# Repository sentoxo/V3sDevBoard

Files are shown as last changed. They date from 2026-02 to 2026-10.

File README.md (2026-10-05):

# V3sDevBoard
Educational project of first PCB desgin, SBC with linux built on allwinner V3s SoC.  

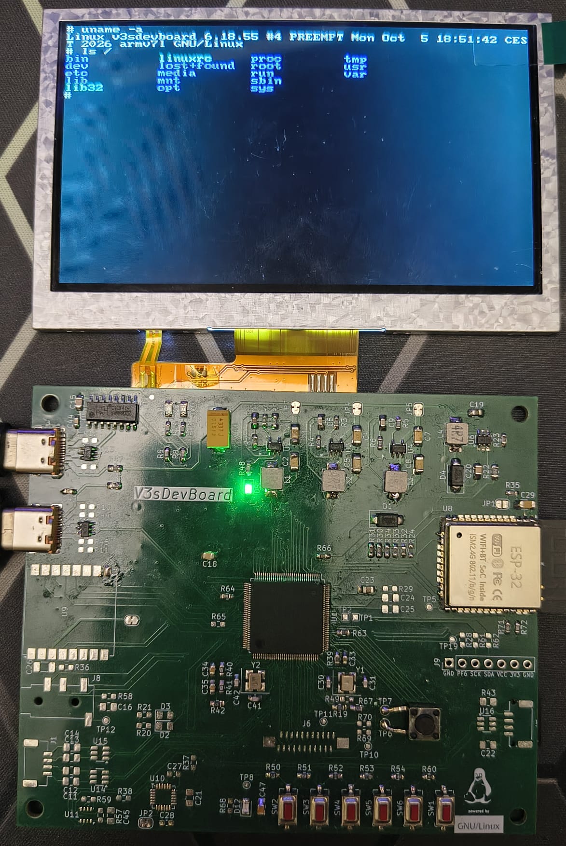
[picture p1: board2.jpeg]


## SYSTEM SPECIFICATIONS
=====================

### CORE SYSTEM:
- CPU: Allwinner V3s (ARM Cortex-A7 @ 1.2GHz)
- RAM: 64MB DDR2 @ 400MHz (Integrated SiP)
- STORAGE: SD Interface for OS (SDIO compatible)

### CONNECTIVITY:
- ETHERNET: 100Mbps Interface
- WIRELESS: WiFi & Bluetooth (via ESP32[ESP-Hosted-NG] on SDIO/UART) {PG0-5 -> SDIO, PB0-1 -> UART}
- LONG RANGE: LoRa support (via Ra-02 on SPI) {PB2 -> RESET, PB3 -> INT, PC0-3 -> SPI}
- USB: USB Host support (Simple)
- DEBUG: System UARTs to USB bridge

### DISPLAY & IMAGING:
- CAMERA: MIPI CSI (22-pin connector)
- LCD: RGB-666 Interface with backlight support (40-pin) [ST7280] {PB4 -> LC_LED_PWM, PE0-19,23-24}

### SENSORS & I/O:
- MOTION: MPU6050 Accelerometer & Gyroscope [I2C] {PB6-7}
- ENVIRONMENT: BME280 Sensor (Temp/Press/Hum) [I2C] {PB6-7}
- AUDIO: 3.5mm Audio Jack
- INPUT: Low-resolution ADC for button matrix (6 buttons)
- VISUAL: PCB RGB backlight WS2812B {PB5}

### POWER & SOFTWARE:
- REGULATION: DC-DC converters for 3.3V, 1.8V, 1.2V
- OPERATING SYSTEM: Powered by custom Mainline Linux

=====================
## Errata for revA
- Ther was mistake in SDIO for SDCard. Swaped data lines.
- RTC didn't have power without battery.

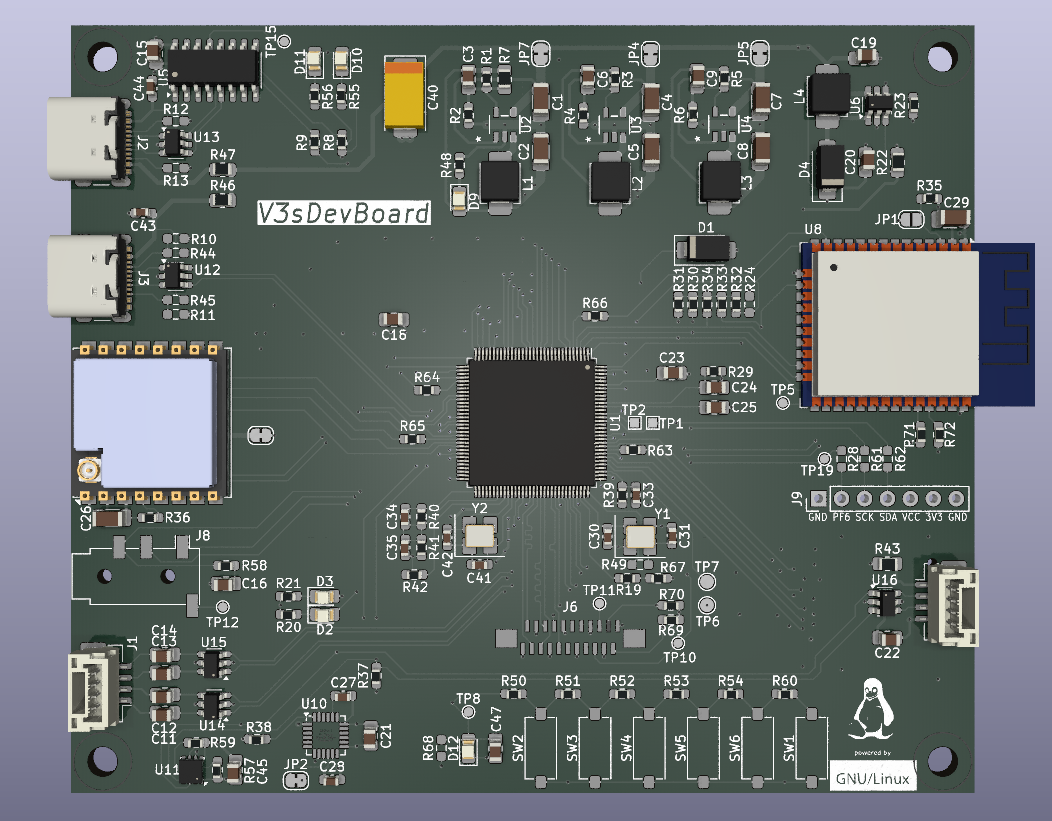
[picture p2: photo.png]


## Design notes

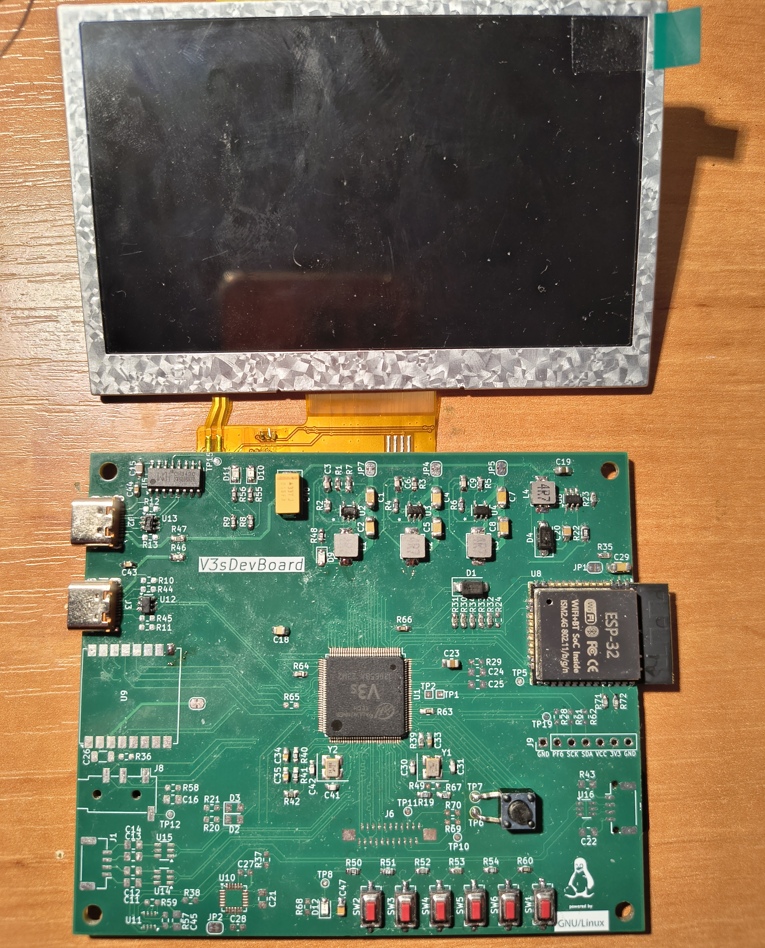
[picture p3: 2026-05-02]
board.jpg

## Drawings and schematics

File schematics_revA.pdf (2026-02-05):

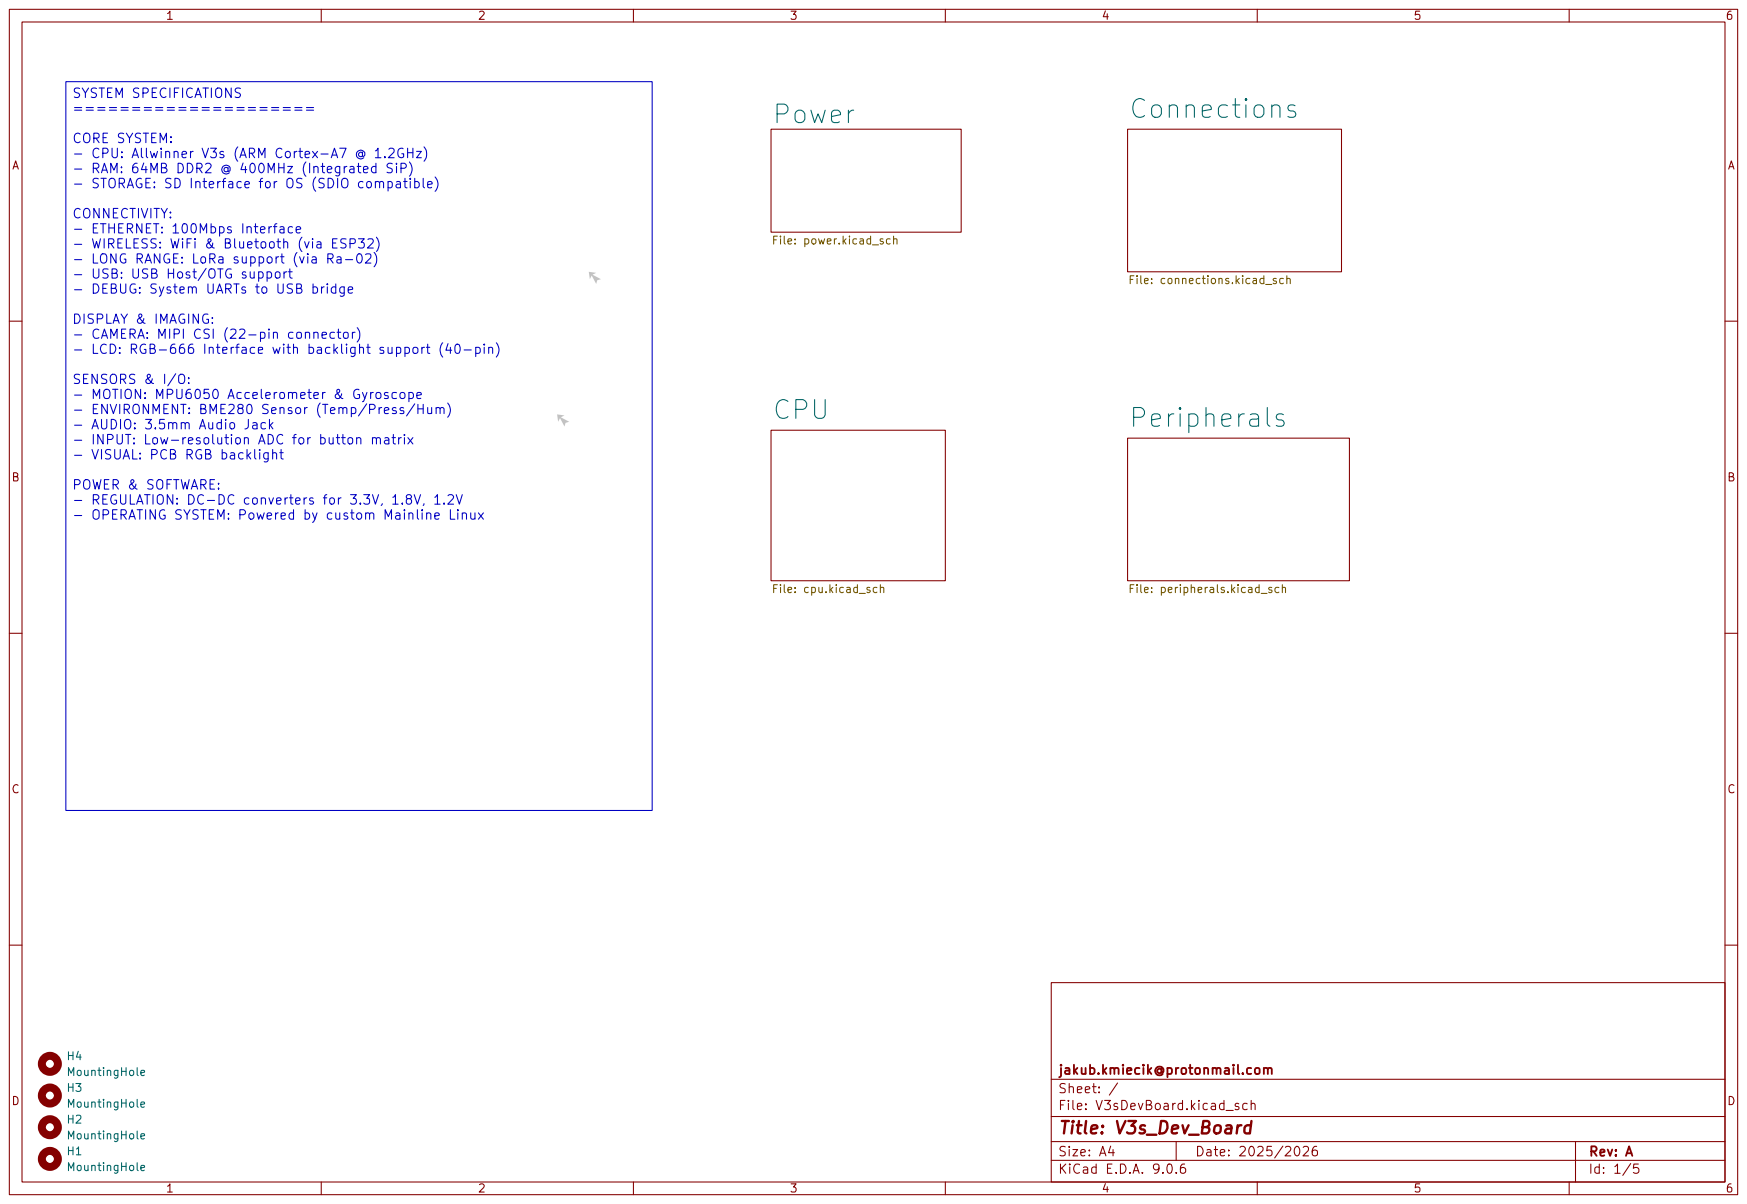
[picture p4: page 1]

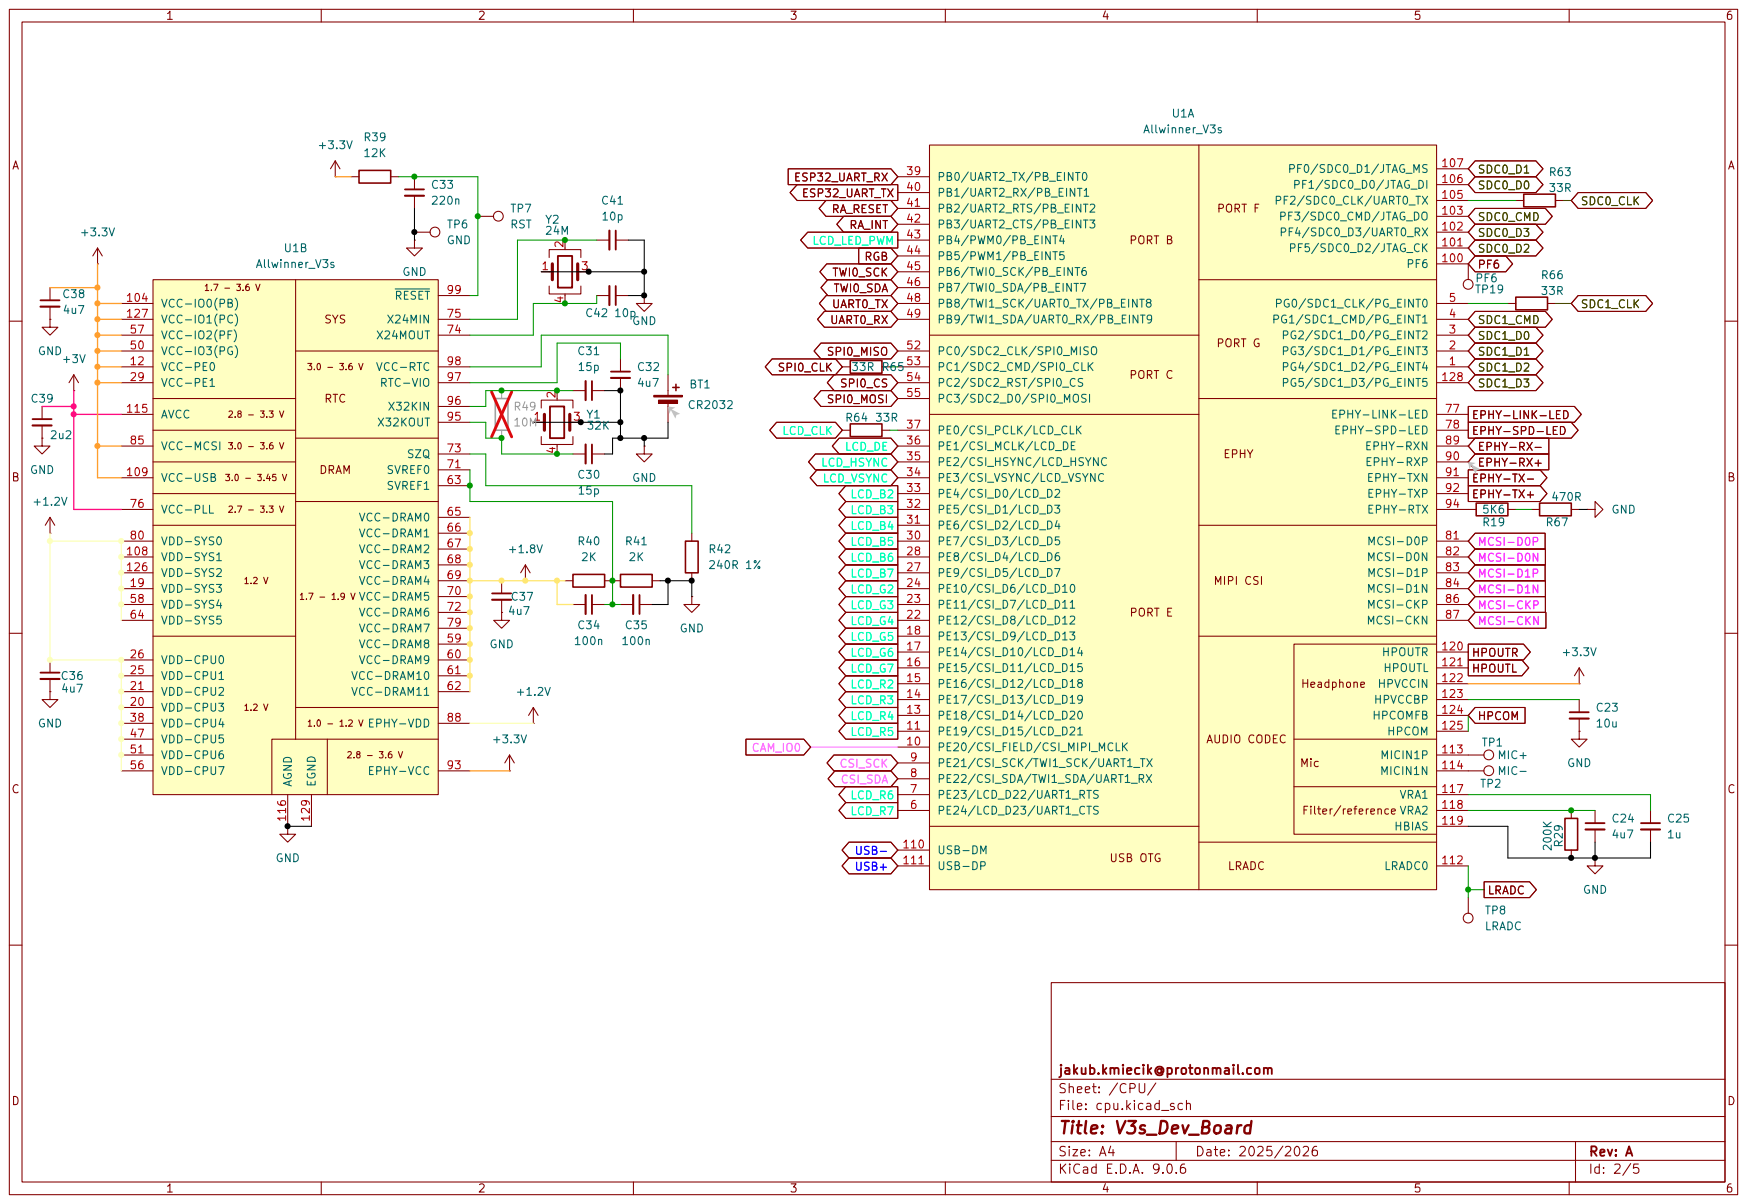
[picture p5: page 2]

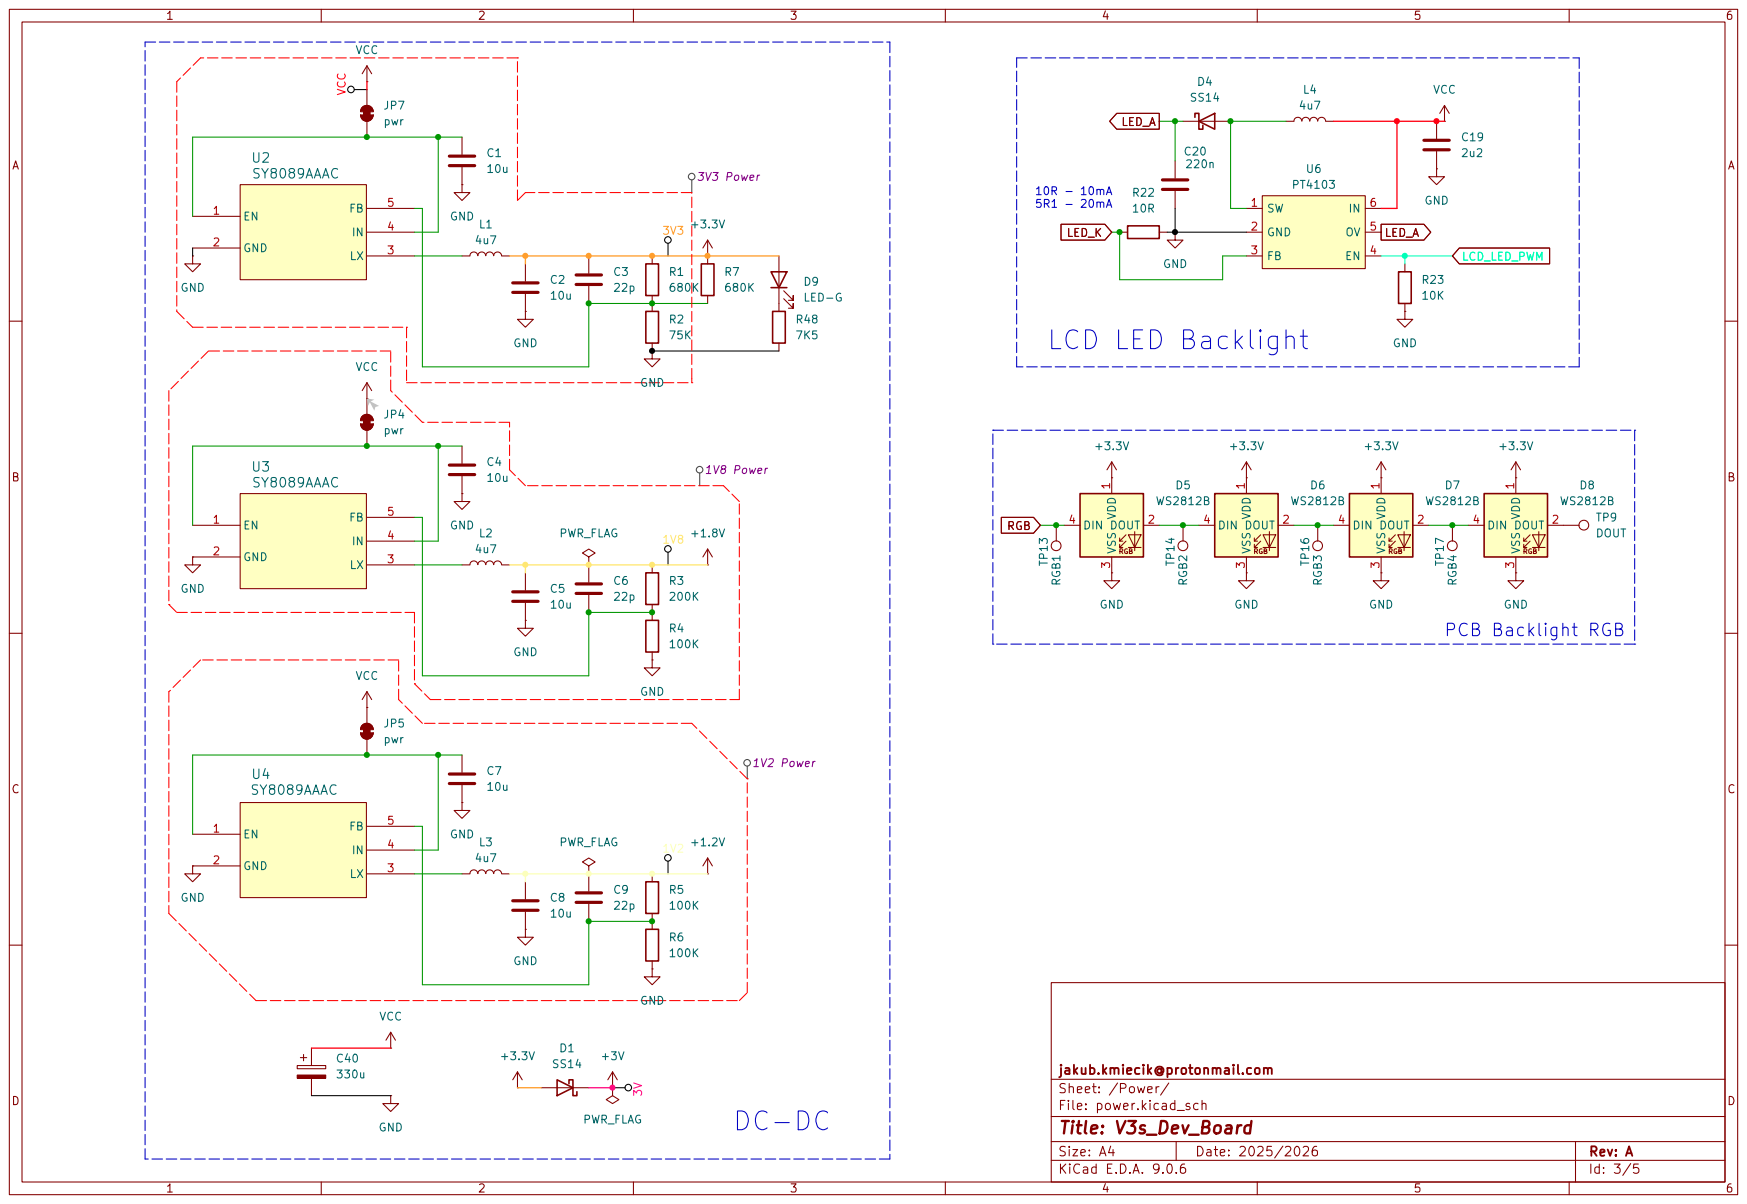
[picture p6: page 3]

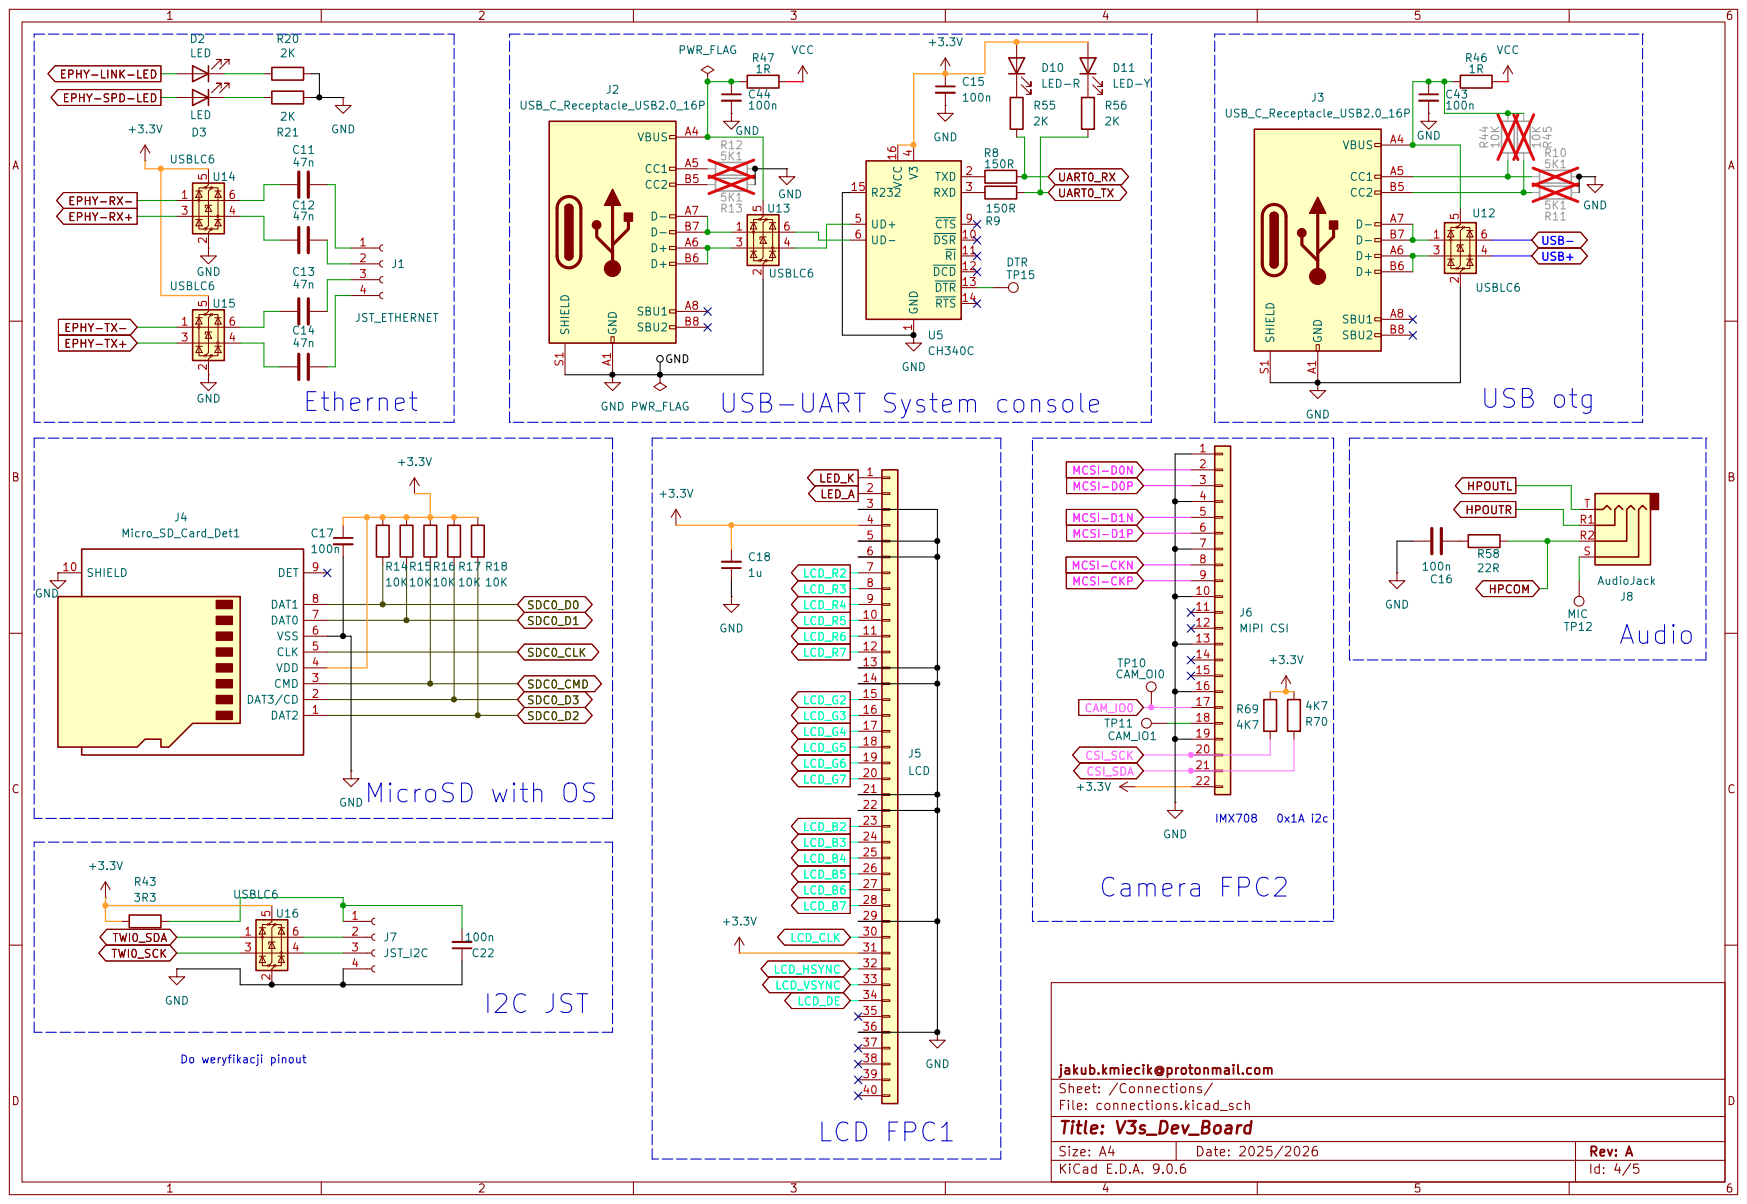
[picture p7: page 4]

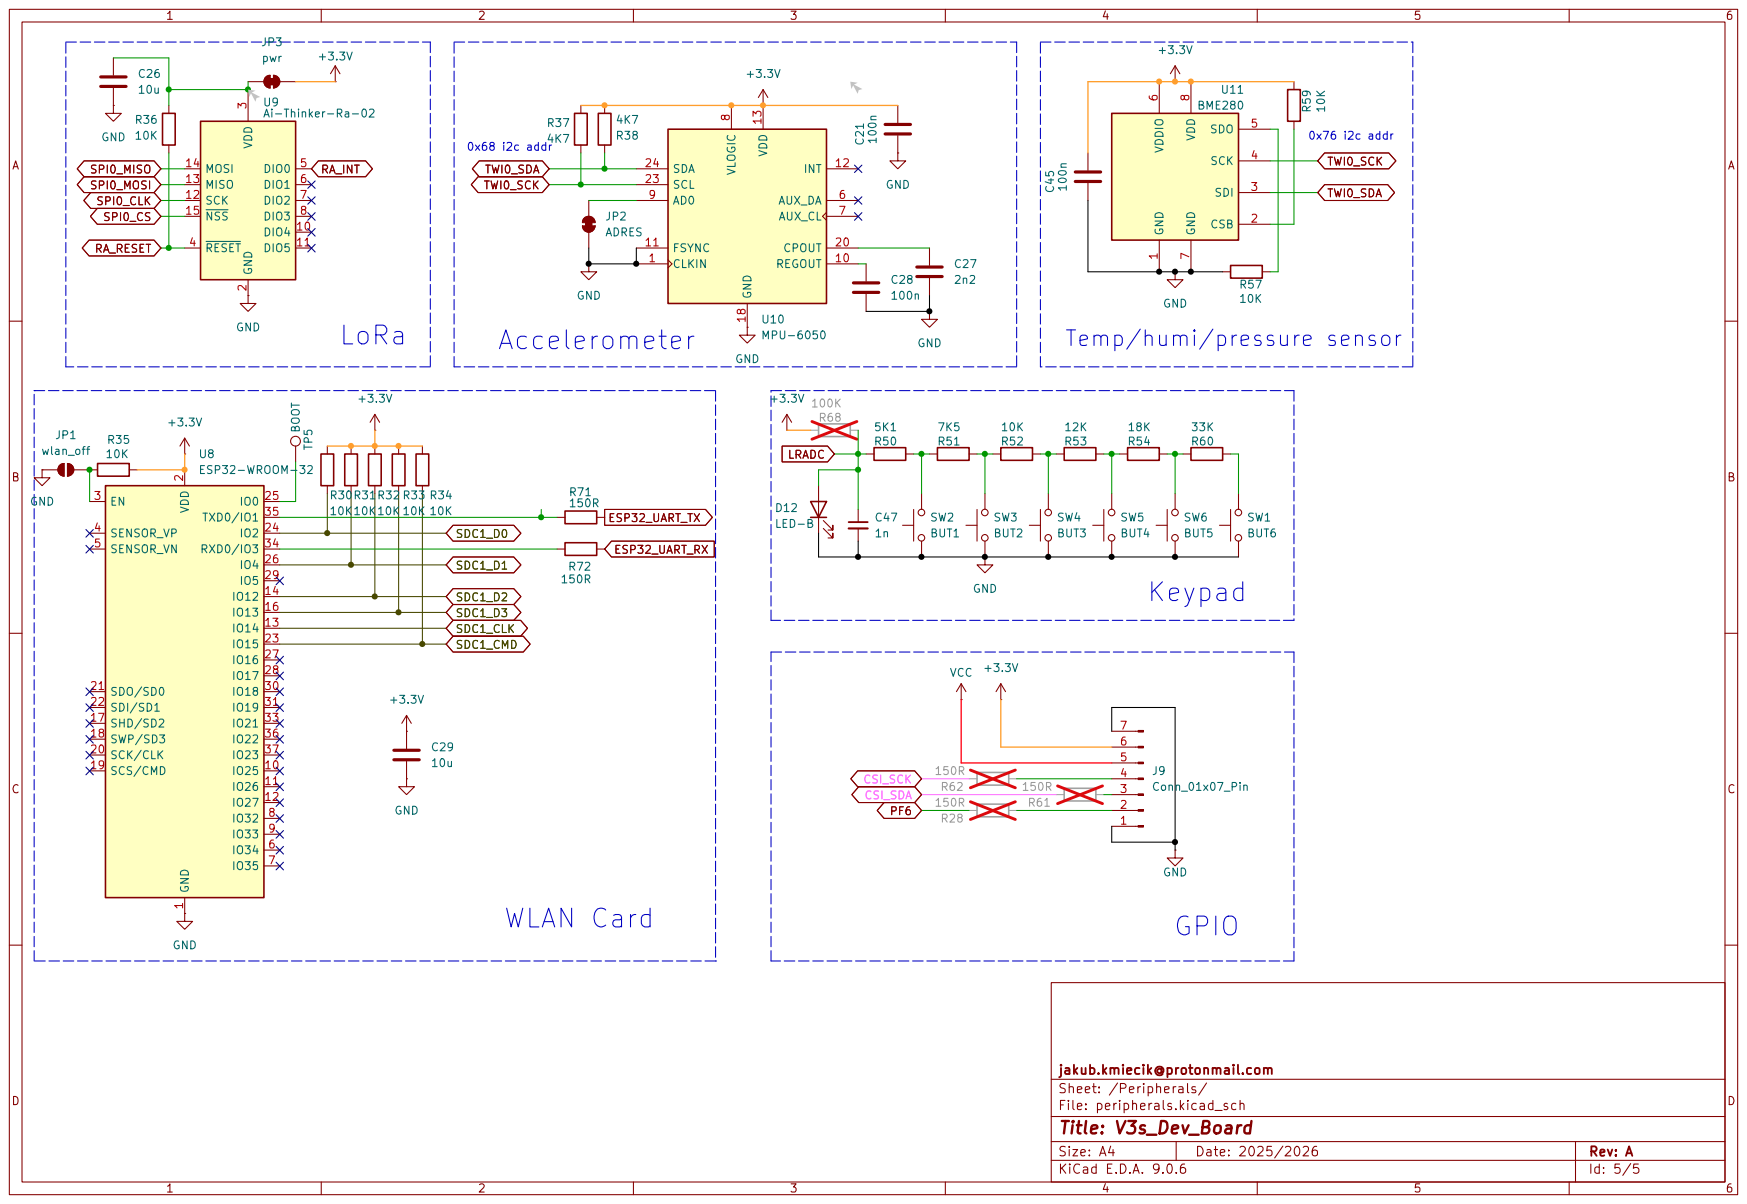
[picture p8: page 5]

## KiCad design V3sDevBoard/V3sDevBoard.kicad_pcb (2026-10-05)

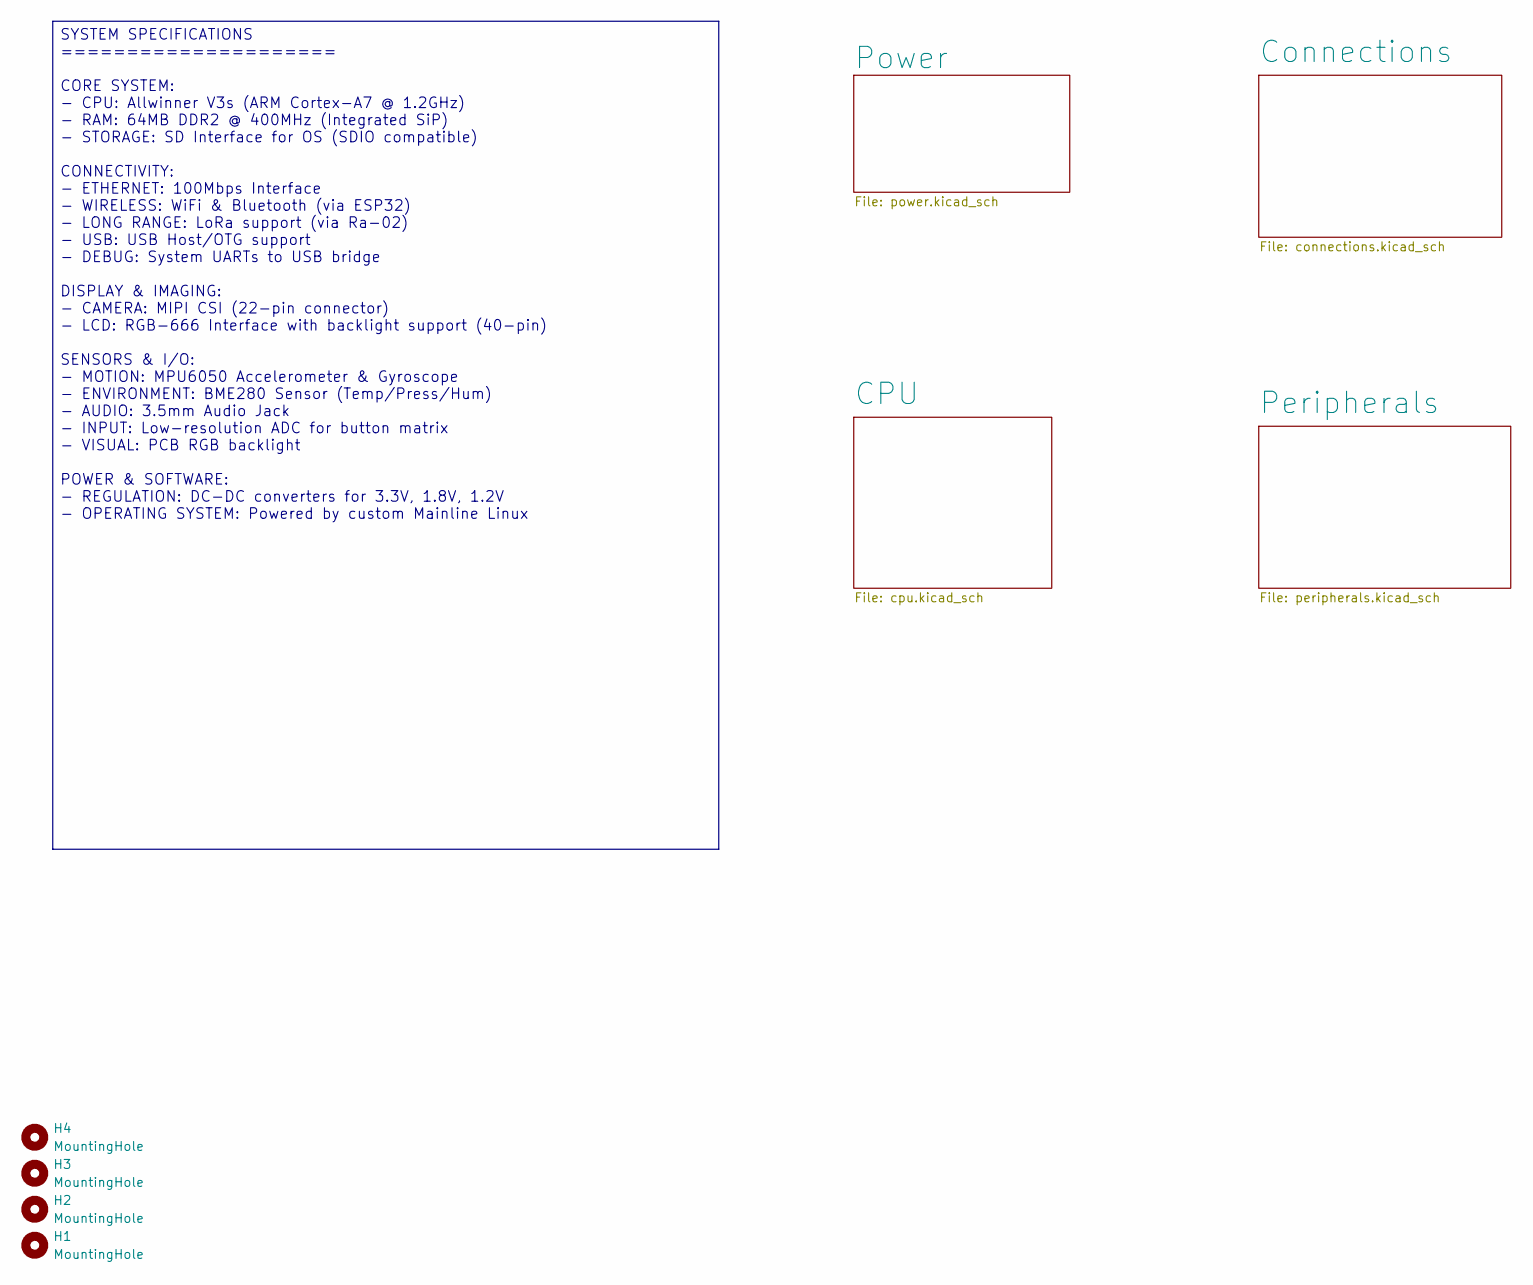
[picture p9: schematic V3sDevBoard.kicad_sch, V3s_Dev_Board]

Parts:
H1, H2, H3, H4: MountingHole; MountingHole_3.2mm_M3

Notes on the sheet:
SYSTEM SPECIFICATIONS ===================== CORE SYSTEM: - CPU: Allwinner V3s (ARM Cortex-A7 @ 1.2GHz) - RAM: 64MB DDR2 @ 400MHz (Integrated SiP) - STORAGE: SD Interface for OS (SDIO compatible) CONNECTIVITY: - ETHERNET: 100Mbps Interface - WIRELESS: WiFi & Bluetooth (via ESP32) - LONG RANGE: LoRa 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

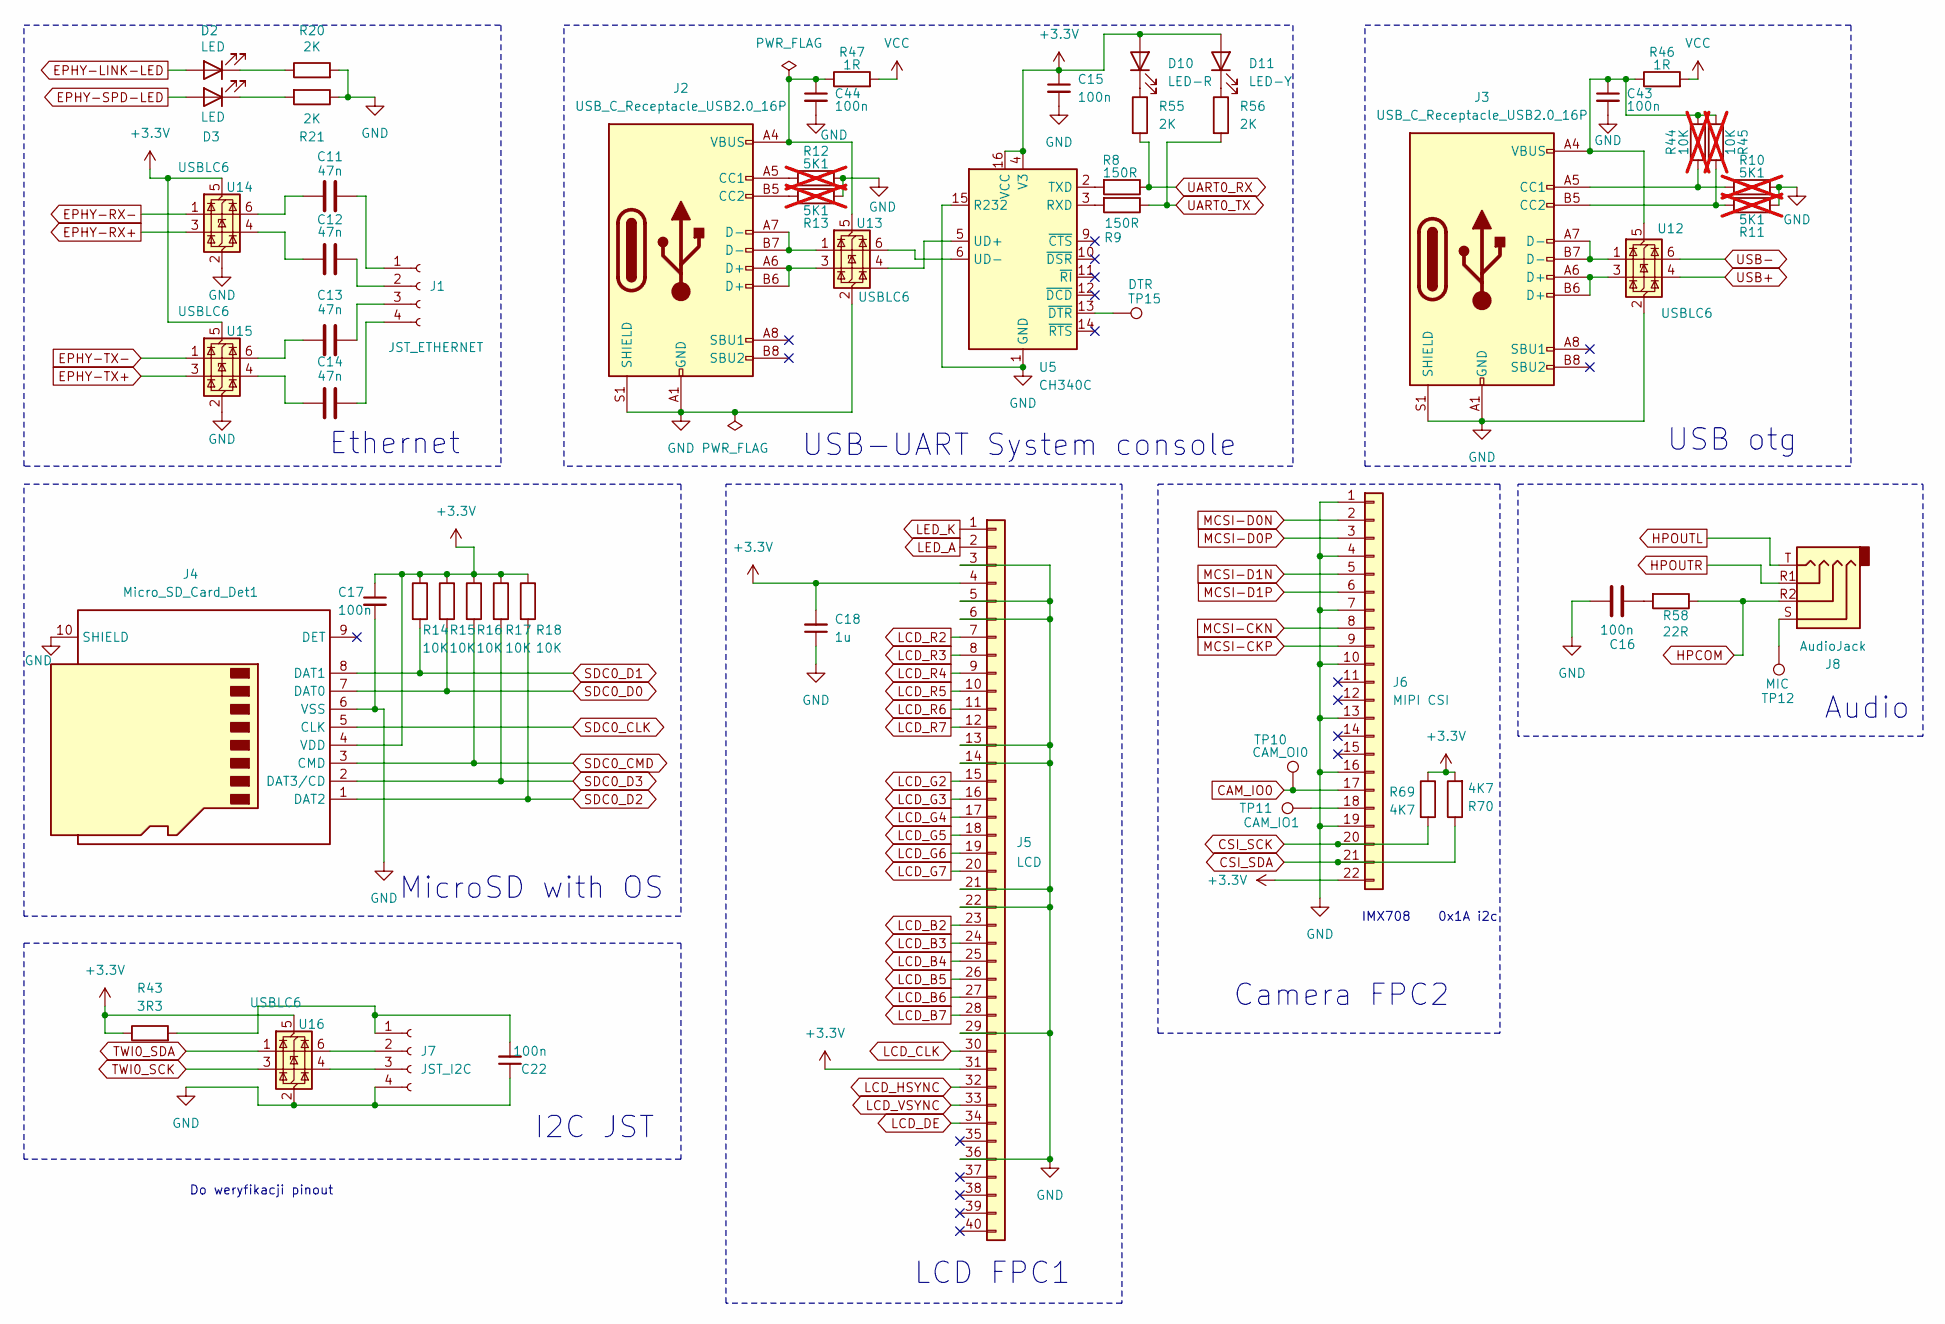
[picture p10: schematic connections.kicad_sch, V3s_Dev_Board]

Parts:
C11, C12, C13, C14: 47n; C_0805_2012Metric_Pad1.18x1.45mm_HandSolder
C15, C16, C17, C22: 100n; C_0805_2012Metric_Pad1.18x1.45mm_HandSolder
C18: 1u; C_0805_2012Metric_Pad1.18x1.45mm_HandSolder
C43, C44: 100n; C_0603_1608Metric_Pad1.08x0.95mm_HandSolder
D2, D3: LED; LED_0805_2012Metric_Pad1.15x1.40mm_HandSolder
D10: LED-R; LED_0805_2012Metric_Pad1.15x1.40mm_HandSolder
D11: LED-Y; LED_0805_2012Metric_Pad1.15x1.40mm_HandSolder
J1: JST_ETHERNET; JST_GH_BM04B-GHS-TBT_1x04-1MP_P1.25mm_Vertical
J2, J3: USB_C_Receptacle_USB2.0_16P; USB_C_Receptacle_GCT_USB4105-xx-A_16P_TopMnt_Horizontal
J4: Micro_SD_Card_Det1; microSD
J5: LCD; Amphenol_F32Q-1A7x1-11040_1x40-1MP_P0.5mm_Horizontal
J6: MIPI CSI; FPC_1x22-1MP_P0.5mm_Vertical
J7: JST_I2C; JST_GH_BM04B-GHS-TBT_1x04-1MP_P1.25mm_Vertical
J8: AudioJack; Jack_3.5mm_PJ320D_Horizontal
R8, R9: 150R; R_0603_1608Metric_Pad0.98x0.95mm_HandSolder
R10, R11, R12, R13: 5K1; R_0603_1608Metric_Pad0.98x0.95mm_HandSolder; not fitted
R14, R15, R16, R17, R18: 10K; R_0603_1608Metric_Pad0.98x0.95mm_HandSolder
R20, R21, R55, R56: 2K; R_0603_1608Metric_Pad0.98x0.95mm_HandSolder
R43: 3R3; R_0805_2012Metric_Pad1.20x1.40mm_HandSolder
R44, R45: 10K; R_0603_1608Metric_Pad0.98x0.95mm_HandSolder; not fitted
R46, R47: 1R; R_0805_2012Metric
R58: 22R; R_0603_1608Metric_Pad0.98x0.95mm_HandSolder
R69, R70: 4K7; R_0603_1608Metric_Pad0.98x0.95mm_HandSolder
TP10: CAM_OI0; TestPoint_Pad_D1.0mm
TP11: CAM_IO1; TestPoint_Pad_D1.0mm
TP12: MIC; TestPoint_Pad_D1.0mm
TP15: DTR; TestPoint_Pad_D1.0mm
U5: CH340C; SOIC-16_3.9x9.9mm_P1.27mm
U12, U13, U14, U15, U16: USBLC6; SOT-23-6

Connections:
+3.3V: C15.1, C17.1, C18.2, D10.2 (A), D11.2 (A), J4.4 (VDD), J5.4, J5.31, J6.22, R14.1, R15.1, R16.1, R17.1, R18.1, R43.1, R69.1, R70.2, U5.4 (V3), U5.16 (VCC), U14.5 (VBUS), U15.5 (VBUS), U16.5 (VBUS); also elsewhere on the board
CAM_IO0: J6.17, TP10.1 (1_1); also elsewhere on the board
CSI_SCK: J6.20, R69.2; also elsewhere on the board
CSI_SDA: J6.21, R70.1; also elsewhere on the board
EPHY-LINK-LED: D2.2 (A); also elsewhere on the board
EPHY-RX+: U14.3 (I/O2); also elsewhere on the board
EPHY-RX-: U14.1 (I/O1); also elsewhere on the board
EPHY-SPD-LED: D3.2 (A); also elsewhere on the board
EPHY-TX+: U15.3 (I/O2); also elsewhere on the board
EPHY-TX-: U15.1 (I/O1); also elsewhere on the board
GND: C15.2, C16.2, C17.2, C18.1, C22.1, C43.2, C44.2, J2.A1 (GND), J2.A12 (GND), J2.B1 (GND), J2.B12 (GND), J2.S1 (SHIELD), J3.A1 (GND), J3.A12 (GND), J3.B1 (GND), J3.B12 (GND), J3.S1 (SHIELD), J4.6 (VSS), J4.10 (SHIELD), J5.3, J5.5, J5.6, J5.13, J5.14, J5.21, J5.22, J5.29, J5.36, J6.1, J6.4, J6.7, J6.10, J6.13, J6.16, J6.19, J7.4, R10.2, R11.1, R12.2, R13.1, R20.2, R21.1, U5.1 (GND), U5.15 (R232), U12.2 (GND), U13.2 (GND), U14.2 (GND), U15.2 (GND), U16.2 (GND); also elsewhere on the board
HPCOM: J8.R2, R58.1; also elsewhere on the board
HPOUTL: J8.T; also elsewhere on the board
HPOUTR: J8.R1; also elsewhere on the board
LCD_B2: J5.23; also elsewhere on the board
LCD_B3: J5.24; also elsewhere on the board
LCD_B4: J5.25; also elsewhere on the board
LCD_B5: J5.26; also elsewhere on the board
LCD_B6: J5.27; also elsewhere on the board
LCD_B7: J5.28; also elsewhere on the board
LCD_CLK: J5.30; also elsewhere on the board
LCD_DE: J5.34; also elsewhere on the board
LCD_G2: J5.15; also elsewhere on the board
LCD_G3: J5.16; also elsewhere on the board
LCD_G4: J5.17; also elsewhere on the board
LCD_G5: J5.18; also elsewhere on the board
LCD_G6: J5.19; also elsewhere on the board
LCD_G7: J5.20; also elsewhere on the board
LCD_HSYNC: J5.32; also elsewhere on the board
LCD_R2: J5.7; also elsewhere on the board
LCD_R3: J5.8; also elsewhere on the board
LCD_R4: J5.9; also elsewhere on the board
LCD_R5: J5.10; also elsewhere on the board
LCD_R6: J5.11; also elsewhere on the board
LCD_R7: J5.12; also elsewhere on the board
LCD_VSYNC: J5.33; also elsewhere on the board
LED_A: J5.2; also elsewhere on the board
LED_K: J5.1; also elsewhere on the board
MCSI-CKN: J6.8; also elsewhere on the board
MCSI-CKP: J6.9; also elsewhere on the board
MCSI-D0N: J6.2; also elsewhere on the board
MCSI-D0P: J6.3; also elsewhere on the board
MCSI-D1N: J6.5; also elsewhere on the board
MCSI-D1P: J6.6; also elsewhere on the board
unnamed: C11.1, U14.6 (I/O1)
unnamed: C12.1, U14.4 (I/O2)
unnamed: C13.1, U15.6 (I/O1)
unnamed: C14.1, U15.4 (I/O2)
unnamed: C16.1, R58.2
unnamed: D2.1 (K), R20.1
unnamed: D3.1 (K), R21.2
unnamed: D10.1 (K), R55.1
unnamed: D11.1 (K), R56.1
unnamed: C11.2, J1.1
unnamed: C12.2, J1.2
unnamed: C13.2, J1.3
unnamed: C14.2, J1.4
unnamed: J2.A5 (CC1), R12.1
unnamed: J2.B5 (CC2), R13.2
unnamed: J2.A6 (D+), J2.B6 (D+), U13.3 (I/O2)
unnamed: J2.A7 (D-), J2.B7 (D-), U13.1 (I/O1)
unnamed: J3.A5 (CC1), R10.1, R44.1
unnamed: J3.B5 (CC2), R11.2, R45.2
unnamed: J3.A6 (D+), J3.B6 (D+), U12.3 (I/O2)
unnamed: J3.A7 (D-), J3.B7 (D-), U12.1 (I/O1)
unnamed: J6.18, TP11.1 (1_1)
unnamed: C22.2, J7.1, R43.2
unnamed: J7.2, U16.6 (I/O1)
unnamed: J7.3, U16.4 (I/O2)
unnamed: J8.S, TP12.1 (1_1)
unnamed: R9.2, U5.3 (RXD)
unnamed: R8.2, U5.2 (TXD)
unnamed: U5.5 (UD+), U13.4 (I/O2)
unnamed: U5.6 (UD-), U13.6 (I/O1)
unnamed: TP15.1 (1_1), U5.13 (~DTR)
unnamed: C43.1, J3.A4 (VBUS), J3.A9 (VBUS), J3.B4 (VBUS), J3.B9 (VBUS), R44.2, R45.1, R46.1, U12.5 (VBUS)
unnamed: C44.1, J2.A4 (VBUS), J2.A9 (VBUS), J2.B4 (VBUS), J2.B9 (VBUS), R47.1, U13.5 (VBUS)
SDC0_CLK: J4.5 (CLK); also elsewhere on the board
SDC0_CMD: J4.3 (CMD), R16.2; also elsewhere on the board
SDC0_D0: J4.7 (DAT0), R15.2; also elsewhere on the board
SDC0_D1: J4.8 (DAT1), R14.2; also elsewhere on the board
SDC0_D2: J4.1 (DAT2), R18.2; also elsewhere on the board
SDC0_D3: J4.2 (DAT3/CD), R17.2; also elsewhere on the board
TWI0_SCK: U16.3 (I/O2); also elsewhere on the board
TWI0_SDA: U16.1 (I/O1); also elsewhere on the board
UART0_RX: R8.1, R55.2; also elsewhere on the board
UART0_TX: R9.1, R56.2; also elsewhere on the board
USB+: U12.4 (I/O2); also elsewhere on the board
USB-: U12.6 (I/O1); also elsewhere on the board
VCC: R46.2, R47.2; also elsewhere on the board

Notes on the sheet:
MicroSD with OS
LCD FPC1
Ethernet
Camera FPC2
USB otg
Audio
IMX708 0x1A i2c
USB-UART System console
Do weryfikacji pinout
I2C JST

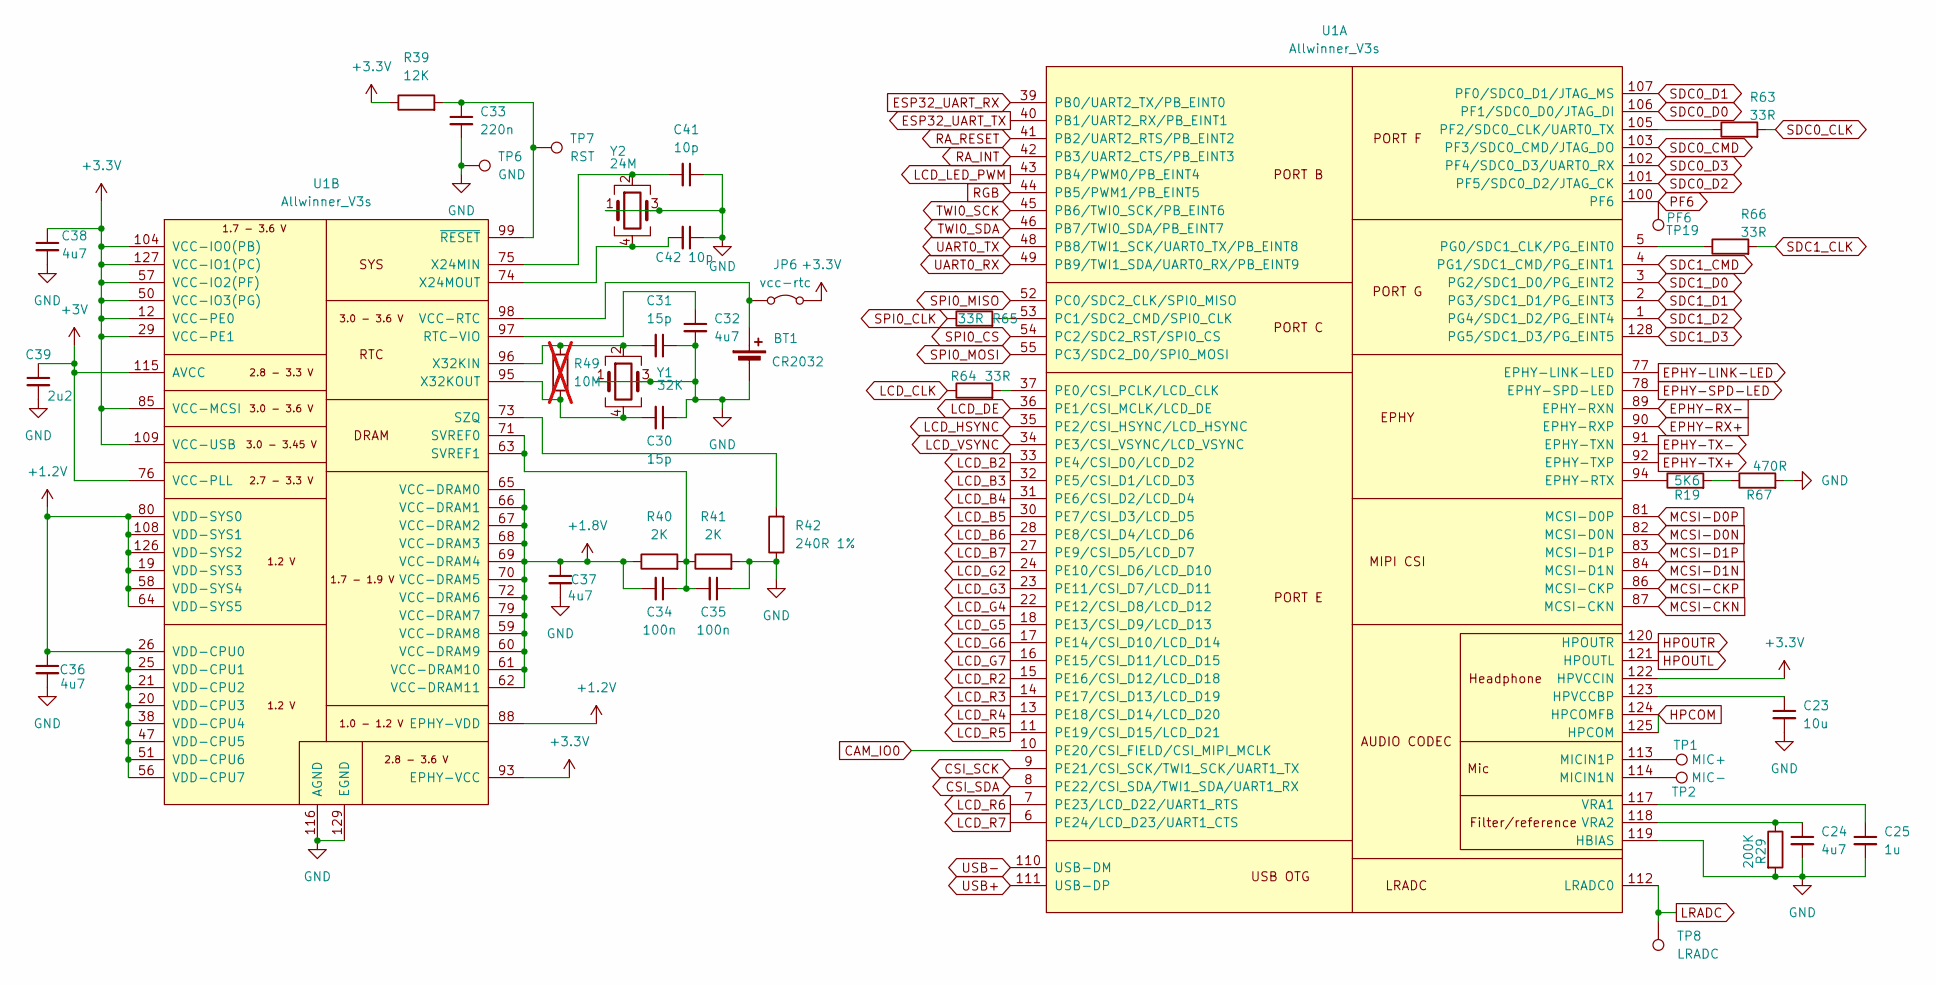
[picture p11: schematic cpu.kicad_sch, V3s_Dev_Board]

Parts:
BT1: CR2032; PinHeader_1x02_P1.00mm_Vertical_SMD_Pin1Right
C23: 10u; C_0805_2012Metric_Pad1.18x1.45mm_HandSolder
C24, C32, C36, C37, C38: 4u7; C_0805_2012Metric_Pad1.18x1.45mm_HandSolder
C25: 1u; C_0805_2012Metric_Pad1.18x1.45mm_HandSolder
C30, C31: 15p; C_0603_1608Metric_Pad1.08x0.95mm_HandSolder
C33: 220n; C_0603_1608Metric_Pad1.08x0.95mm_HandSolder
C34, C35: 100n; C_0603_1608Metric_Pad1.08x0.95mm_HandSolder
C39: 2u2; C_0805_2012Metric_Pad1.18x1.45mm_HandSolder
C41, C42: 10p; C_0603_1608Metric_Pad1.08x0.95mm_HandSolder
JP6: vcc-rtc; SolderJumper-2_P1.3mm_Bridged_RoundedPad1.0x1.5mm
R19: 5K6; R_0603_1608Metric_Pad0.98x0.95mm_HandSolder
R29: 200K; R_0603_1608Metric_Pad0.98x0.95mm_HandSolder
R39: 12K; R_0603_1608Metric_Pad0.98x0.95mm_HandSolder
R40, R41: 2K; R_0603_1608Metric_Pad0.98x0.95mm_HandSolder
R42: 240R 1%; R_0603_1608Metric_Pad0.98x0.95mm_HandSolder
R49: 10M; R_0603_1608Metric_Pad0.98x0.95mm_HandSolder; not fitted
R63, R64, R65, R66: 33R; R_0603_1608Metric_Pad0.98x0.95mm_HandSolder
R67: 470R; R_0603_1608Metric_Pad0.98x0.95mm_HandSolder
TP1: MIC+; TestPoint_Pad_1.0x1.0mm
TP2: MIC-; TestPoint_Pad_1.0x1.0mm
TP6: GND; TestPoint_Pad_D1.5mm
TP7: RST; TestPoint_Pad_D1.5mm
TP8: LRADC; TestPoint_Pad_D1.0mm
TP19: PF6; TestPoint_Pad_D1.0mm
U1: Allwinner_V3s; eLQFP-128_14x14_Pitch0.4mm_EPAD_6.60mm
Y1: 32K; Crystal_SMD_3225-4Pin_3.2x2.5mm_HandSoldering
Y2: 24M; Crystal_SMD_3225-4Pin_3.2x2.5mm_HandSoldering

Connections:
+1.2V: C36.1, U1.19 (VDD-SYS3), U1.20 (VDD-CPU3), U1.21 (VDD-CPU2), U1.25 (VDD-CPU1), U1.26 (VDD-CPU0), U1.38 (VDD-CPU4), U1.47 (VDD-CPU5), U1.51 (VDD-CPU6), U1.56 (VDD-CPU7), U1.58 (VDD-SYS4), U1.64 (VDD-SYS5), U1.80 (VDD-SYS0), U1.88 (EPHY-VDD), U1.108 (VDD-SYS1), U1.126 (VDD-SYS2); also elsewhere on the board
+1.8V: C34.2, C37.1, R40.1, U1.59 (VCC-DRAM8), U1.60 (VCC-DRAM9), U1.61 (VCC-DRAM10), U1.62 (VCC-DRAM11), U1.65 (VCC-DRAM0), U1.66 (VCC-DRAM1), U1.67 (VCC-DRAM2), U1.68 (VCC-DRAM3), U1.69 (VCC-DRAM4), U1.70 (VCC-DRAM5), U1.72 (VCC-DRAM6), U1.79 (VCC-DRAM7); also elsewhere on the board
+3.3V: C38.1, JP6.2 (B), R39.1, U1.12 (VCC-PE0), U1.29 (VCC-PE1), U1.50 (VCC-IO3(PG)), U1.57 (VCC-IO2(PF)), U1.85 (VCC-MCSI), U1.93 (EPHY-VCC), U1.104 (VCC-IO0(PB)), U1.109 (VCC-USB), U1.122 (HPVCCIN), U1.127 (VCC-IO1(PC)); also elsewhere on the board
+3V: C39.1, U1.76 (VCC-PLL), U1.115 (AVCC); also elsewhere on the board
CAM_IO0: U1.10 (PE20/CSI_FIELD/CSI_MIPI_MCLK); also elsewhere on the board
CSI_SCK: U1.9 (PE21/CSI_SCK/TWI1_SCK/UART1_TX); also elsewhere on the board
CSI_SDA: U1.8 (PE22/CSI_SDA/TWI1_SDA/UART1_RX); also elsewhere on the board
EPHY-LINK-LED: U1.77 (EPHY-LINK-LED); also elsewhere on the board
EPHY-RX+: U1.90 (EPHY-RXP); also elsewhere on the board
EPHY-RX-: U1.89 (EPHY-RXN); also elsewhere on the board
EPHY-SPD-LED: U1.78 (EPHY-SPD-LED); also elsewhere on the board
EPHY-TX+: U1.92 (EPHY-TXP); also elsewhere on the board
EPHY-TX-: U1.91 (EPHY-TXN); also elsewhere on the board
ESP32_UART_RX: U1.39 (PB0/UART2_TX/PB_EINT0); also elsewhere on the board
ESP32_UART_TX: U1.40 (PB1/UART2_RX/PB_EINT1); also elsewhere on the board
GND: BT1.2 (-), C23.2, C24.2, C25.2, C30.1, C31.1, C32.2, C33.2, C35.1, C36.2, C37.2, C38.2, C39.2, C41.1, C42.1, R29.2, R41.2, R42.1, R67.2, TP6.1 (1_1), U1.116 (AGND), U1.119 (HBIAS), U1.129 (EGND), Y1.1, Y1.3, Y2.1, Y2.3; also elsewhere on the board
HPCOM: U1.124 (HPCOMFB), U1.125 (HPCOM); also elsewhere on the board
HPOUTL: U1.121 (HPOUTL); also elsewhere on the board
HPOUTR: U1.120 (HPOUTR); also elsewhere on the board
LCD_B2: U1.33 (PE4/CSI_D0/LCD_D2); also elsewhere on the board
LCD_B3: U1.32 (PE5/CSI_D1/LCD_D3); also elsewhere on the board
LCD_B4: U1.31 (PE6/CSI_D2/LCD_D4); also elsewhere on the board
LCD_B5: U1.30 (PE7/CSI_D3/LCD_D5); also elsewhere on the board
LCD_B6: U1.28 (PE8/CSI_D4/LCD_D6); also elsewhere on the board
LCD_B7: U1.27 (PE9/CSI_D5/LCD_D7); also elsewhere on the board
LCD_CLK: R64.1; also elsewhere on the board
LCD_DE: U1.36 (PE1/CSI_MCLK/LCD_DE); also elsewhere on the board
LCD_G2: U1.24 (PE10/CSI_D6/LCD_D10); also elsewhere on the board
LCD_G3: U1.23 (PE11/CSI_D7/LCD_D11); also elsewhere on the board
LCD_G4: U1.22 (PE12/CSI_D8/LCD_D12); also elsewhere on the board
LCD_G5: U1.18 (PE13/CSI_D9/LCD_D13); also elsewhere on the board
LCD_G6: U1.17 (PE14/CSI_D10/LCD_D14); also elsewhere on the board
LCD_G7: U1.16 (PE15/CSI_D11/LCD_D15); also elsewhere on the board
LCD_HSYNC: U1.35 (PE2/CSI_HSYNC/LCD_HSYNC); also elsewhere on the board
LCD_LED_PWM: U1.43 (PB4/PWM0/PB_EINT4); also elsewhere on the board
LCD_R2: U1.15 (PE16/CSI_D12/LCD_D18); also elsewhere on the board
LCD_R3: U1.14 (PE17/CSI_D13/LCD_D19); also elsewhere on the board
LCD_R4: U1.13 (PE18/CSI_D14/LCD_D20); also elsewhere on the board
LCD_R5: U1.11 (PE19/CSI_D15/LCD_D21); also elsewhere on the board
LCD_R6: U1.7 (PE23/LCD_D22/UART1_RTS); also elsewhere on the board
LCD_R7: U1.6 (PE24/LCD_D23/UART1_CTS); also elsewhere on the board
LCD_VSYNC: U1.34 (PE3/CSI_VSYNC/LCD_VSYNC); also elsewhere on the board
LRADC: TP8.1 (1_1), U1.112 (LRADC0); also elsewhere on the board
MCSI-CKN: U1.87 (MCSI-CKN); also elsewhere on the board
MCSI-CKP: U1.86 (MCSI-CKP); also elsewhere on the board
MCSI-D0N: U1.82 (MCSI-D0N); also elsewhere on the board
MCSI-D0P: U1.81 (MCSI-D0P); also elsewhere on the board
MCSI-D1N: U1.84 (MCSI-D1N); also elsewhere on the board
MCSI-D1P: U1.83 (MCSI-D1P); also elsewhere on the board
unnamed: BT1.1 (+), JP6.1 (A), U1.98 (VCC-RTC)
unnamed: R19.2, R67.1
unnamed: R19.1, U1.94 (EPHY-RTX)
unnamed: C23.1, U1.123 (HPVCCBP)
unnamed: TP2.1 (1_1), U1.114 (MICIN1N)
unnamed: TP1.1 (1_1), U1.113 (MICIN1P)
unnamed: R65.2, U1.53 (PC1/SDC2_CMD/SPI0_CLK)
unnamed: R64.2, U1.37 (PE0/CSI_PCLK/LCD_CLK)
unnamed: R63.1, U1.105 (PF2/SDC0_CLK/UART0_TX)
unnamed: R66.1, U1.5 (PG0/SDC1_CLK/PG_EINT0)
unnamed: C25.1, U1.117 (VRA1)
unnamed: C24.1, R29.1, U1.118 (VRA2)
unnamed: C32.1, U1.97 (RTC-VIO)
unnamed: C34.1, C35.2, R40.2, R41.1, U1.63 (SVREF1), U1.71 (SVREF0)
unnamed: R42.2, U1.73 (SZQ)
unnamed: C41.2, U1.75 (X24MIN), Y2.2
unnamed: C42.2, U1.74 (X24MOUT), Y2.4
unnamed: C31.2, R49.2, U1.96 (X32KIN), Y1.2
unnamed: C30.2, R49.1, U1.95 (X32KOUT), Y1.4
unnamed: C33.1, R39.2, TP7.1 (1_1), U1.99 (~RESET)
PF6: TP19.1 (1_1), U1.100 (PF6); also elsewhere on the board
RA_INT: U1.42 (PB3/UART2_CTS/PB_EINT3); also elsewhere on the board
RA_RESET: U1.41 (PB2/UART2_RTS/PB_EINT2); also elsewhere on the board
RGB: U1.44 (PB5/PWM1/PB_EINT5); also elsewhere on the board
SDC0_CLK: R63.2; also elsewhere on the board
SDC0_CMD: U1.103 (PF3/SDC0_CMD/JTAG_DO); also elsewhere on the board
SDC0_D0: U1.106 (PF1/SDC0_D0/JTAG_DI); also elsewhere on the board
SDC0_D1: U1.107 (PF0/SDC0_D1/JTAG_MS); also elsewhere on the board
SDC0_D2: U1.101 (PF5/SDC0_D2/JTAG_CK); also elsewhere on the board
SDC0_D3: U1.102 (PF4/SDC0_D3/UART0_RX); also elsewhere on the board
SDC1_CLK: R66.2; also elsewhere on the board
SDC1_CMD: U1.4 (PG1/SDC1_CMD/PG_EINT1); also elsewhere on the board
SDC1_D0: U1.3 (PG2/SDC1_D0/PG_EINT2); also elsewhere on the board
SDC1_D1: U1.2 (PG3/SDC1_D1/PG_EINT3); also elsewhere on the board
SDC1_D2: U1.1 (PG4/SDC1_D2/PG_EINT4); also elsewhere on the board
SDC1_D3: U1.128 (PG5/SDC1_D3/PG_EINT5); also elsewhere on the board
SPI0_CLK: R65.1; also elsewhere on the board
SPI0_CS: U1.54 (PC2/SDC2_RST/SPI0_CS); also elsewhere on the board
SPI0_MISO: U1.52 (PC0/SDC2_CLK/SPI0_MISO); also elsewhere on the board
SPI0_MOSI: U1.55 (PC3/SDC2_D0/SPI0_MOSI); also elsewhere on the board
TWI0_SCK: U1.45 (PB6/TWI0_SCK/PB_EINT6); also elsewhere on the board
TWI0_SDA: U1.46 (PB7/TWI0_SDA/PB_EINT7); also elsewhere on the board
UART0_RX: U1.49 (PB9/TWI1_SDA/UART0_RX/PB_EINT9); also elsewhere on the board
UART0_TX: U1.48 (PB8/TWI1_SCK/UART0_TX/PB_EINT8); also elsewhere on the board
USB+: U1.111 (USB-DP); also elsewhere on the board
USB-: U1.110 (USB-DM); also elsewhere on the board

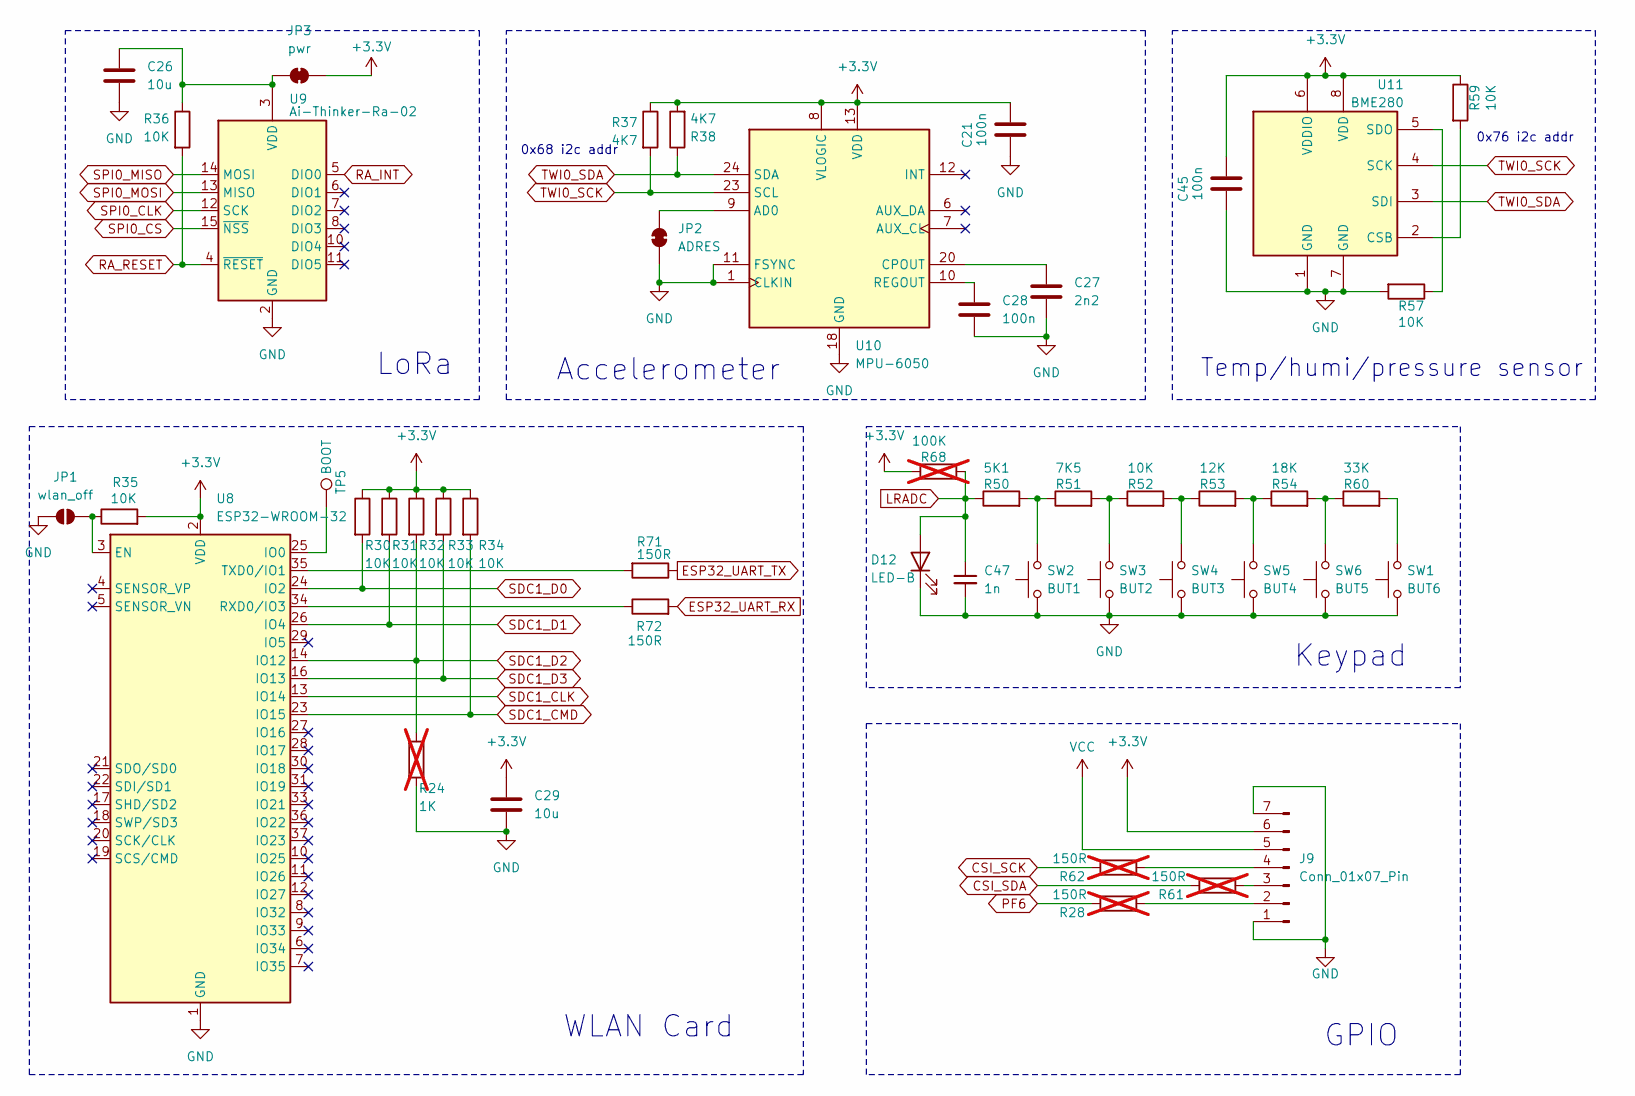
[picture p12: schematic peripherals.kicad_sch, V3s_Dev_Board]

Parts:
C21, C45: 100n; C_0805_2012Metric_Pad1.18x1.45mm_HandSolder
C26, C29: 10u; C_1206_3216Metric
C27: 2n2; C_0603_1608Metric_Pad1.08x0.95mm_HandSolder
C28: 100n; C_0603_1608Metric_Pad1.08x0.95mm_HandSolder
C47: 1n; C_0805_2012Metric_Pad1.18x1.45mm_HandSolder
D12: LED-B; LED_0805_2012Metric_Pad1.15x1.40mm_HandSolder
J9: Conn_01x07_Pin; PinHeader_1x07_P2.54mm_Vertical
JP1: wlan_off; SolderJumper-2_P1.3mm_Open_RoundedPad1.0x1.5mm
JP2: ADRES; SolderJumper-2_P1.3mm_Bridged_RoundedPad1.0x1.5mm
JP3: pwr; SolderJumper-2_P1.3mm_Bridged_RoundedPad1.0x1.5mm
R24: 1K; R_0603_1608Metric_Pad0.98x0.95mm_HandSolder; not fitted
R28, R61, R62: 150R; R_0603_1608Metric_Pad0.98x0.95mm_HandSolder; not fitted
R30, R31, R32, R33, R34, R35, R36, R52, R57, R59: 10K; R_0603_1608Metric_Pad0.98x0.95mm_HandSolder
R37, R38: 4K7; R_0603_1608Metric_Pad0.98x0.95mm_HandSolder
R50: 5K1; R_0603_1608Metric_Pad0.98x0.95mm_HandSolder
R51: 7K5; R_0603_1608Metric_Pad0.98x0.95mm_HandSolder
R53: 12K; R_0603_1608Metric_Pad0.98x0.95mm_HandSolder
R54: 18K; R_0603_1608Metric_Pad0.98x0.95mm_HandSolder
R60: 33K; R_0603_1608Metric_Pad0.98x0.95mm_HandSolder
R68: 100K; R_0603_1608Metric_Pad0.98x0.95mm_HandSolder; not fitted
R71, R72: 150R; R_0603_1608Metric_Pad0.98x0.95mm_HandSolder
SW1: BUT6; Button_6x3mm
SW2: BUT1; Button_6x3mm
SW3: BUT2; Button_6x3mm
SW4: BUT3; Button_6x3mm
SW5: BUT4; Button_6x3mm
SW6: BUT5; Button_6x3mm
TP5: BOOT; TestPoint_Pad_D1.0mm
U8: ESP32-WROOM-32
U9: Ai-Thinker-Ra-02; Ai-Thinker-Ra-01-LoRa
U10: MPU-6050; InvenSense_QFN-24_4x4mm_P0.5mm
U11: BME280; Bosch_LGA-8_2.5x2.5mm_P0.65mm_ClockwisePinNumbering

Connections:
+3.3V: C21.2, C29.1, C45.2, J9.6, JP3.1 (A), R30.1, R31.1, R32.1, R33.1, R34.1, R35.2, R37.1, R38.2, R59.1, R68.1, U8.2 (VDD), U10.8 (VLOGIC), U10.13 (VDD), U11.6 (VDDIO), U11.8 (VDD); also elsewhere on the board
CSI_SCK: R62.1; also elsewhere on the board
CSI_SDA: R61.1; also elsewhere on the board
ESP32_UART_RX: R72.2; also elsewhere on the board
ESP32_UART_TX: R71.1; also elsewhere on the board
GND: C21.1, C26.2, C27.2, C28.2, C29.2, C45.1, C47.2, D12.1 (K), J9.1, J9.7, JP1.1 (A), JP2.2 (B), R24.2, R57.2, SW1.1, SW2.1, SW3.1, SW4.1, SW5.1, SW6.1, U8.1 (GND), U8.15 (GND), U8.38 (GND), U8.39 (GND), U9.1 (GND), U9.2 (GND), U9.9 (GND), U9.16 (GND), U10.1 (CLKIN), U10.11 (FSYNC), U10.18 (GND), U11.1 (GND), U11.7 (GND); also elsewhere on the board
LRADC: C47.1, D12.2 (A), R50.1, R68.2; also elsewhere on the board
unnamed: J9.2, R28.2
unnamed: J9.3, R61.2
unnamed: J9.4, R62.2
unnamed: JP1.2 (B), R35.1, U8.3 (EN)
unnamed: JP2.1 (A), U10.9 (AD0)
unnamed: C26.1, JP3.2 (B), R36.1, U9.3 (VDD)
unnamed: R50.2, R51.1, SW2.2
unnamed: R51.2, R52.1, SW3.2
unnamed: R52.2, R53.1, SW4.2
unnamed: R53.2, R54.1, SW5.2
unnamed: R54.2, R60.1, SW6.2
unnamed: R60.2, SW1.2
unnamed: TP5.1 (1_1), U8.25 (IO0)
unnamed: R72.1, U8.34 (RXD0/IO3)
unnamed: R71.2, U8.35 (TXD0/IO1)
unnamed: C27.1, U10.20 (CPOUT)
unnamed: C28.1, U10.10 (REGOUT)
unnamed: R59.2, U11.2 (CSB)
unnamed: R57.1, U11.5 (SDO)
PF6: R28.1; also elsewhere on the board
RA_INT: U9.5 (DIO0); also elsewhere on the board
RA_RESET: R36.2, U9.4 (~RESET); also elsewhere on the board
SDC1_CLK: U8.13 (IO14); also elsewhere on the board
SDC1_CMD: R34.2, U8.23 (IO15); also elsewhere on the board
SDC1_D0: R30.2, U8.24 (IO2); also elsewhere on the board
SDC1_D1: R31.2, U8.26 (IO4); also elsewhere on the board
SDC1_D2: R24.1, R32.2, U8.14 (IO12); also elsewhere on the board
SDC1_D3: R33.2, U8.16 (IO13); also elsewhere on the board
SPI0_CLK: U9.12 (SCK); also elsewhere on the board
SPI0_CS: U9.15 (~NSS); also elsewhere on the board
SPI0_MISO: U9.14 (MOSI); also elsewhere on the board
SPI0_MOSI: U9.13 (MISO); also elsewhere on the board
TWI0_SCK: R37.2, U10.23 (SCL), U11.4 (SCK); also elsewhere on the board
TWI0_SDA: R38.1, U10.24 (SDA), U11.3 (SDI); also elsewhere on the board
VCC: J9.5; also elsewhere on the board

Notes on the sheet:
0x68 i2c addr
Keypad
LoRa
Temp/humi/pressure sensor
0x76 i2c addr
WLAN Card
Accelerometer
GPIO

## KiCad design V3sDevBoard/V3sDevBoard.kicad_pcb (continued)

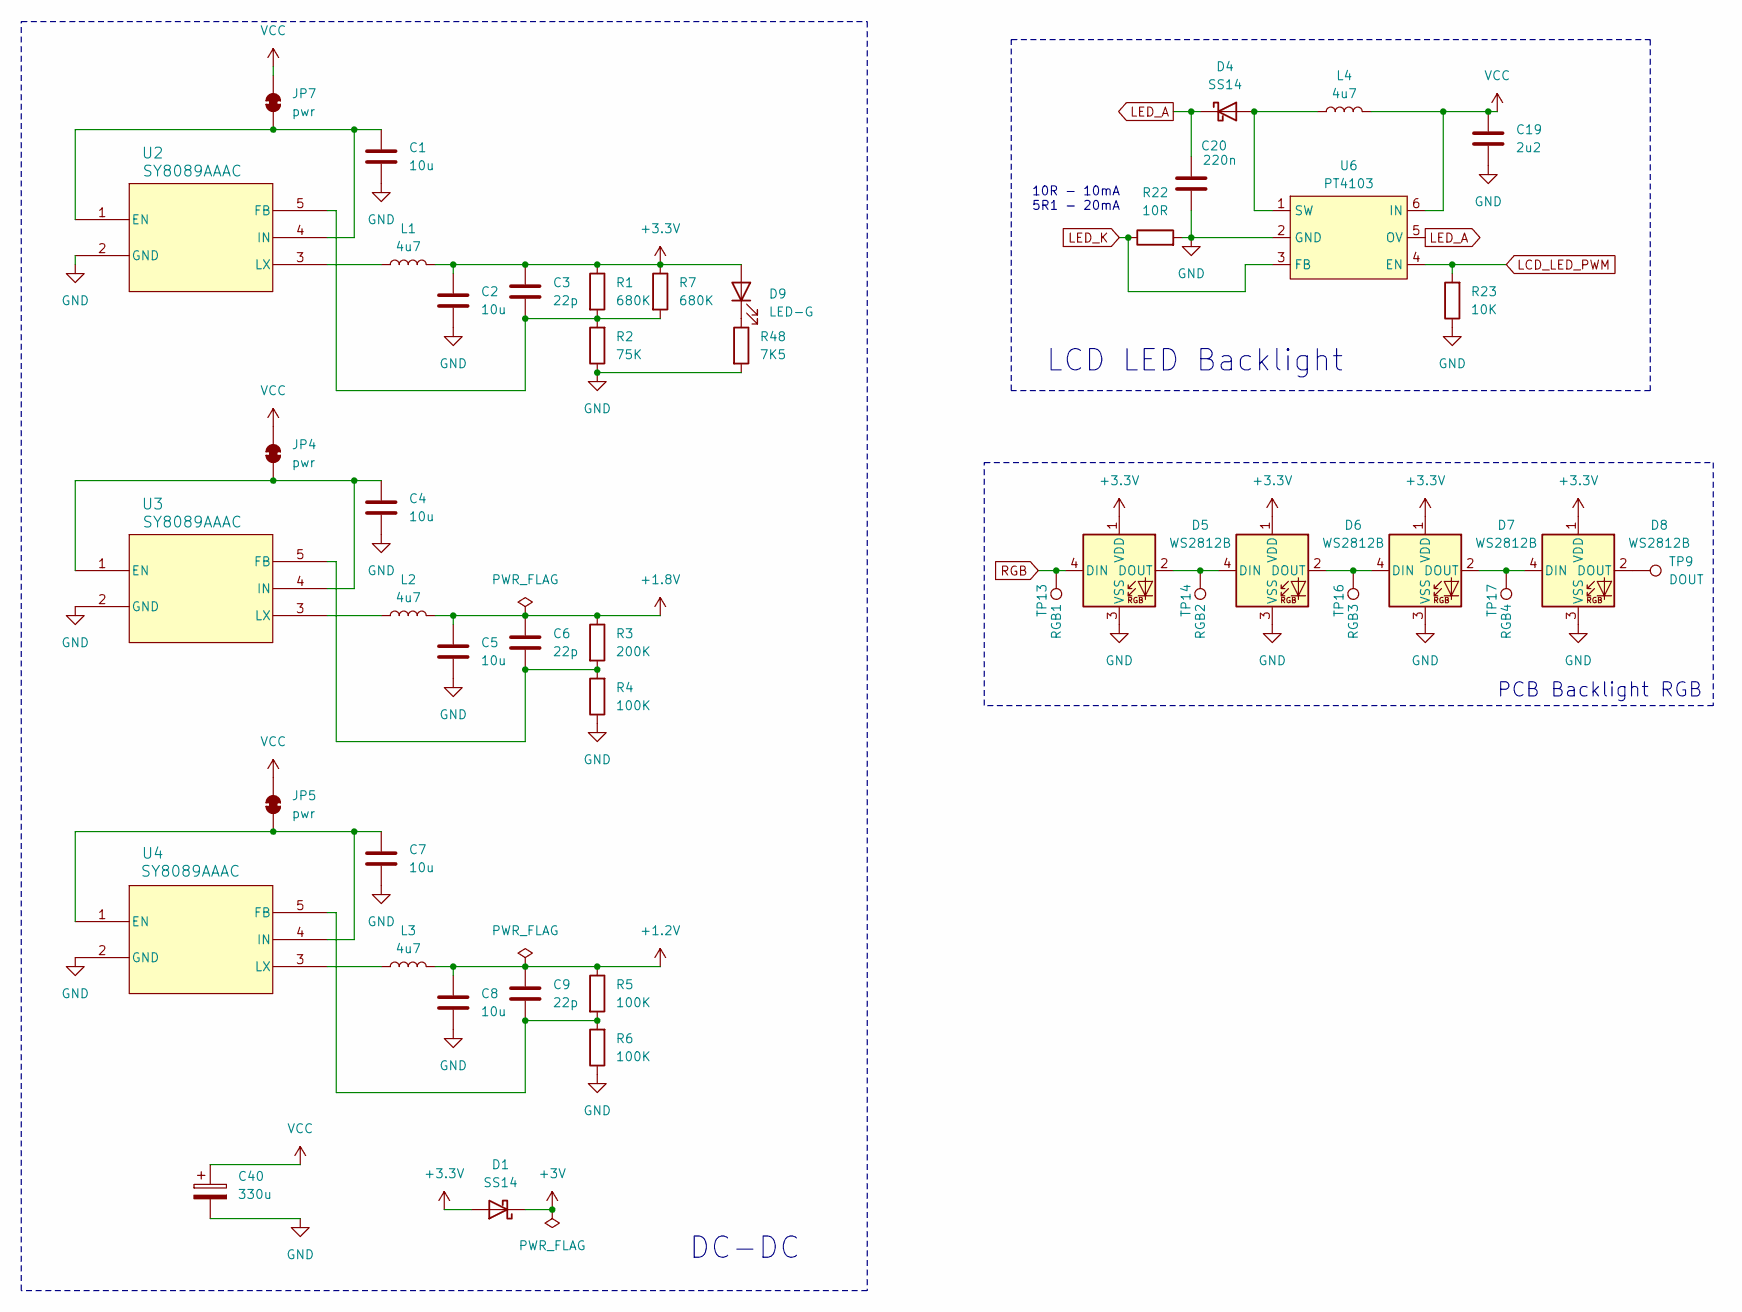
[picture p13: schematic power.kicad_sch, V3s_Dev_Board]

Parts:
C1, C2, C4, C5, C7, C8: 10u; C_1206_3216Metric
C3, C6, C9: 22p; C_0805_2012Metric_Pad1.18x1.45mm_HandSolder
C19: 2u2; C_0805_2012Metric_Pad1.18x1.45mm_HandSolder
C20: 220n; C_0805_2012Metric_Pad1.18x1.45mm_HandSolder
C40: 330u; CP_EIA-7343-15_Kemet-W_HandSolder
D1, D4: SS14; D_SMA
D5, D6, D7, D8: WS2812B; LED_WS2812B_PLCC4_5.0x5.0mm_P3.2mm
D9: LED-G; LED_0805_2012Metric_Pad1.15x1.40mm_HandSolder
JP4, JP5, JP7: pwr; SolderJumper-2_P1.3mm_Bridged_RoundedPad1.0x1.5mm
L1, L2, L3, L4: 4u7; L_APV_APH0420_HandSolder
R1: 680K; R_0603_1608Metric_Pad0.98x0.95mm_HandSolder
R2: 75K; R_0603_1608Metric_Pad0.98x0.95mm_HandSolder
R3: 200K; R_0603_1608Metric_Pad0.98x0.95mm_HandSolder
R4, R5, R6: 100K; R_0603_1608Metric_Pad0.98x0.95mm_HandSolder
R7: 680K; R_0805_2012Metric_Pad1.20x1.40mm_HandSolder
R22: 10R; R_0805_2012Metric_Pad1.20x1.40mm_HandSolder
R23: 10K; R_0603_1608Metric_Pad0.98x0.95mm_HandSolder
R48: 7K5; R_0603_1608Metric_Pad0.98x0.95mm_HandSolder
TP9: DOUT; TestPoint_Pad_D1.0mm
TP13: RGB1; TestPoint_Pad_D1.0mm
TP14: RGB2; TestPoint_Pad_D1.0mm
TP16: RGB3; TestPoint_Pad_D1.0mm
TP17: RGB4; TestPoint_Pad_D1.0mm
U2, U3, U4: SY8089AAAC; SY8089AAAC_SGY
U6: PT4103; SOT-23-6_Handsoldering

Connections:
+1.2V: C8.1, C9.1, L3.2, R5.1; also elsewhere on the board
+1.8V: C5.1, C6.1, L2.2, R3.1; also elsewhere on the board
+3.3V: C2.1, C3.1, D1.2 (A), D5.1 (VDD), D6.1 (VDD), D7.1 (VDD), D8.1 (VDD), D9.2 (A), L1.2, R1.1, R7.1; also elsewhere on the board
+3V: D1.1 (K); also elsewhere on the board
GND: C1.2, C2.2, C4.2, C5.2, C7.2, C8.2, C19.2, C20.2, C40.2, D5.3 (VSS), D6.3 (VSS), D7.3 (VSS), D8.3 (VSS), R2.1, R4.1, R6.1, R22.2, R23.1, R48.2, U2.2 (GND), U3.2 (GND), U4.2 (GND), U6.2 (GND); also elsewhere on the board
LCD_LED_PWM: R23.2, U6.4 (EN); also elsewhere on the board
LED_A: C20.1, D4.1 (K), U6.5 (OV); also elsewhere on the board
LED_K: R22.1, U6.3 (FB); also elsewhere on the board
unnamed: D4.2 (A), L4.1, U6.1 (SW)
unnamed: D5.2 (DOUT), D6.4 (DIN), TP14.1 (1_1)
unnamed: D6.2 (DOUT), D7.4 (DIN), TP16.1 (1_1)
unnamed: D7.2 (DOUT), D8.4 (DIN), TP17.1 (1_1)
unnamed: D8.2 (DOUT), TP9.1 (1_1)
unnamed: D9.1 (K), R48.1
unnamed: C4.1, JP4.1 (A), U3.1 (EN), U3.4 (IN)
unnamed: C7.1, JP5.1 (A), U4.1 (EN), U4.4 (IN)
unnamed: C1.1, JP7.1 (A), U2.1 (EN), U2.4 (IN)
unnamed: C3.2, R1.2, R2.2, R7.2, U2.5 (FB)
unnamed: L1.1, U2.3 (LX)
unnamed: C6.2, R3.2, R4.2, U3.5 (FB)
unnamed: L2.1, U3.3 (LX)
unnamed: C9.2, R5.2, R6.2, U4.5 (FB)
unnamed: L3.1, U4.3 (LX)
RGB: D5.4 (DIN), TP13.1 (1_1); also elsewhere on the board
VCC: C19.1, C40.1, JP4.2 (B), JP5.2 (B), JP7.2 (B), L4.2, U6.6 (IN); also elsewhere on the board

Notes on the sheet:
10R - 10mA 5R1 - 20mA
LCD LED Backlight
PCB Backlight RGB
DC-DC

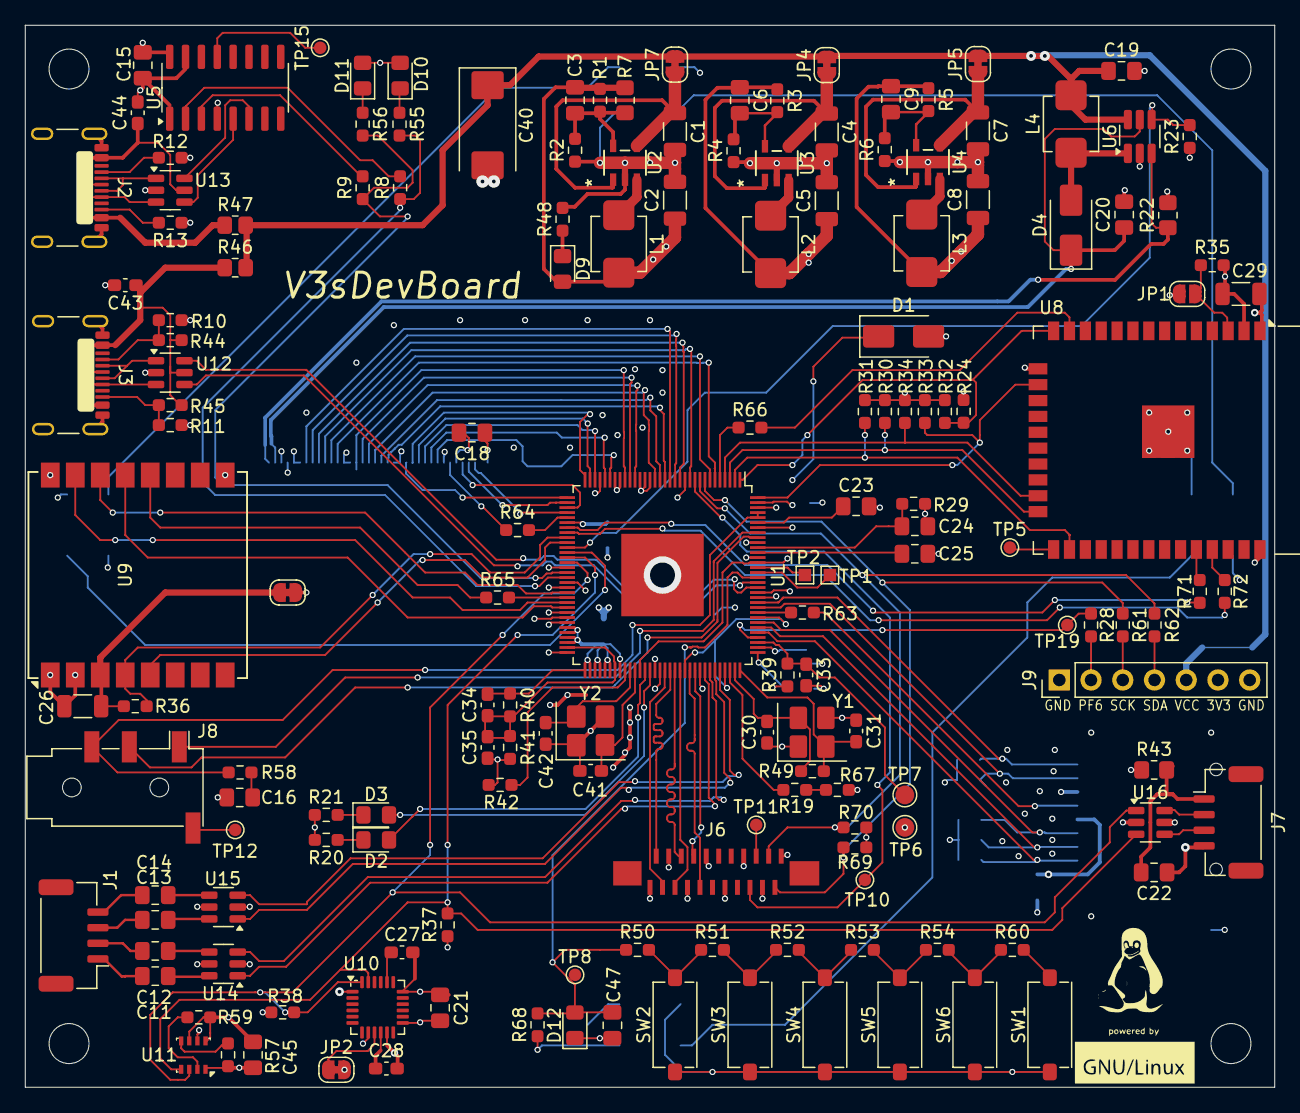
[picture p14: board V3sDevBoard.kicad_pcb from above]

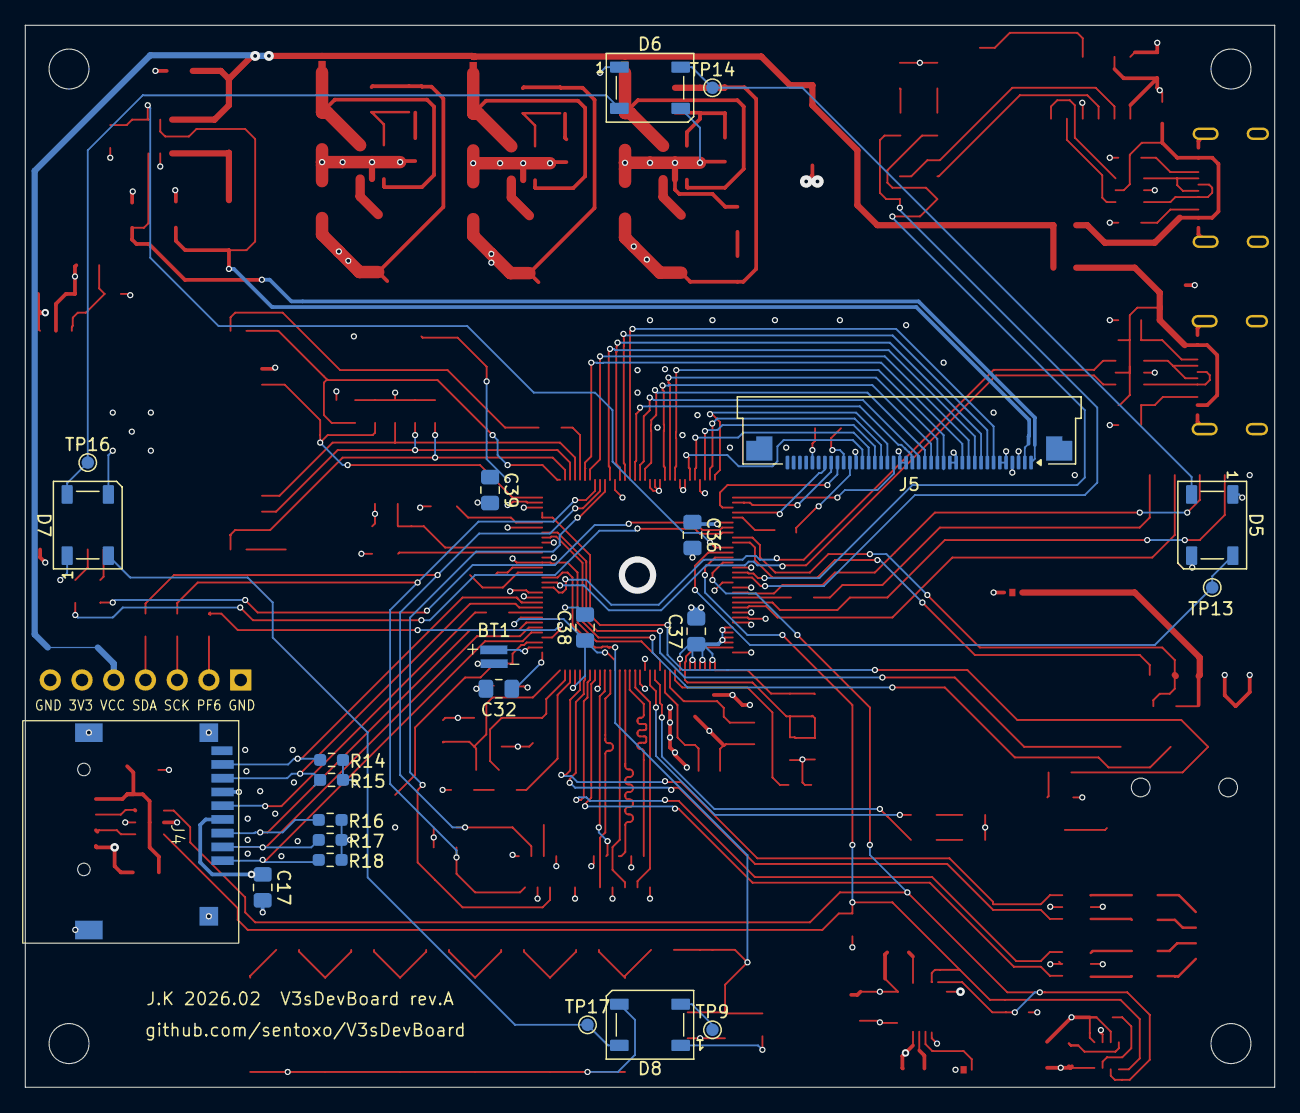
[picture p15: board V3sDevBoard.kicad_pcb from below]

Board: 4 copper layers, 100.0 x 85.0 mm, 189 parts (23 on the bottom side), 165 nets.

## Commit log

2025-12-24 drawing schematic
    [V3sDevBoard.kicad_sch, connections.kicad_sch, cpu.kicad_sch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]
2025-12-25 drawing schematics
    [V3sDevBoard.kicad_sch, connections.kicad_sch, cpu.kicad_sch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]
2025-12-26 advancing in schematics and footprints
    Making needed custom footprints for connectors, adding a lot of small changes to schematics.
    [V3sDevBoard.kicad_sch, connections.kicad_sch, cpu.kicad_sch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]
2025-12-28 completing schematics
    completing schematics, adding netclasses, fixing bugs, updating readme, starting pcb
    [V3sDevBoard.kicad_pcb, V3sDevBoard.kicad_sch, connections.kicad_sch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]
2025-12-30 first attempts to arrange components on a PCB
    plus making footprints bme280&mpu6050 easier to hand solder.
    [V3sDevBoard.kicad_pcb, connections.kicad_sch, cpu.kicad_sch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]
2026-02-05 completing pcb desgin
    Returning to project after month away. Switching to 4-layer desgin on 3313 stackup sig-gnd-pow-sig, changing size of some passive to 0603, connecting all components, adding silkscreen.
    [V3sDevBoard.kicad_pcb, connections.kicad_sch, cpu.kicad_sch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]
2026-02-16 last changes and sending to manufacturing
    [V3sDevBoard.kicad_pcb, peripherals.kicad_sch]
2026-05-02 fixing errors in revA
    Fixing:
    - Ther was mistake in SDIO for SDCard. Swaped data lines.
    - RTC didn't have power without battery.
    Updating readme.
    [V3sDevBoard.kicad_pcb, V3sDevBoard.kicad_sch, connections.kicad_sch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]
